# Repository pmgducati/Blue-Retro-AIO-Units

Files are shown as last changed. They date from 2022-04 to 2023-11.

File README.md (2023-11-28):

# Blue Retro AIO PCBs
This is a collection of PCBs that I made to work with darthcloud's BlueRetro Project. (https://github.com/darthcloud/BlueRetro)  The PCB's were created in Eagle and I have included the Gerbers if you would like to build them yourself. 

I have created PCB's for all supported systems with the exception of JVS.  An issue has been created for each of the systems that need testing.  If you make one please comment in the related issue on any progress/issues.

Currently, I am working on the Virtual Boy PCB, but need to find a cost efficient controller plug (I am not consolizing mine).  

Amaiorano wrote up a review for the variants that they built, you can read it here:
https://amaiorano.io/2023/11/06/blueretro-aio.html

Current status of all systems:


Here are some pics of the PCBs and Housings:









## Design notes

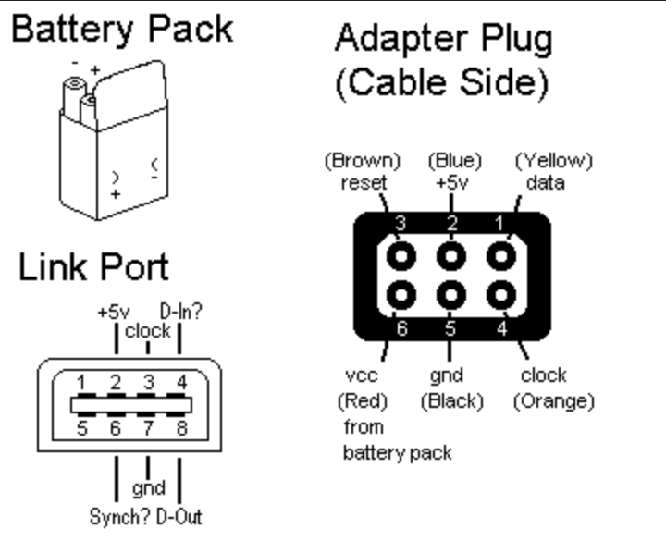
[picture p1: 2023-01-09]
Datasheets/Screenshot 2022-12-22 112040.png

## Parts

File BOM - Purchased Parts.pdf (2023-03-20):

Main PCB:
Part # | Digikey Part # | Description | Qty | ID | Notes | Link
DB25-PL-24 | 2057-DB25-PL-24-ND | DB25 Male solder cup | 1 | X1 | | https://www.digikey.com/en/products/detail/adam-tech/DB25-PL-24/9832321
ESP32-DEVKITC-32E | 1965-ESP32-DEVKITC-32E-ND | ESP32-WROOM-32E 4MB FLASH
LTST-C150TBKT | 160-1643-1-ND | Blue LED | 1 | LED1 | | https://www.digikey.com/en/products/detail/lite-on-inc/LTST-C150TBKT/388526
ERJ-8ENF84R5V | P84.5FCT-ND | 84.5 Ohm Resistor | 1 | R1 | | https://www.digikey.com/en/products/detail/panasonic-electronic-components/ERJ-8ENF84R5V/88656
801-43-019-10-001000 | ED6350-19-ND | CONN RCPT 19POS 0.1 GOLD PC | 2 | | Optional but recommended, if not using make sure the FW is good before soldering ESP32 to PCB | https://www.digikey.com/en/products/detail/mill-max-manufacturing-corp/801-43-019-10-001000/1212256
1 | U1 | ESP32 | https://www.digikey.com/en/products/detail/espressif-systems/ESP32-DEVKITC-32E/12091810

Atari 2600 (PP/OD)
Part # | Digikey Part # | Description | Qty | ID | Notes | Link
DB25-SL-24 | 2057-DB25-SL-24-ND | DB25 Female solder cup | 1 | X1 | | https://www.digikey.com/en/products/detail/adam-tech/DB25-SL-24/9832422
SN74AHCT125N | 296-4655-5-ND | 74AHCT125N DIP14 | 3 | U1,U2,U3 | | https://www.digikey.com/en/products/detail/texas-instruments/SN74AHCT125N/375798
| | Extension Cable | 2 | | Can Find Different options on Amazon | https://console5.com/store/atari-sega-commodore-coleco-msx-6-1-8m-joystick-controller-project-repair-cable-cord.html

Atari 7800
Part # | Digikey Part # | Description | Qty | ID | Notes | Link
DB25-SL-24 | 2057-DB25-SL-24-ND | DB25 Female solder cup | 1 | X1 | | https://www.digikey.com/en/products/detail/adam-tech/DB25-SL-24/9832422
SN74AHCT125N | 296-4655-5-ND | 74AHCT125N DIP14 | 3 | U1,U2,U3 | | https://www.digikey.com/en/products/detail/texas-instruments/SN74AHCT125N/375798
| | Extension Cable | 2 | | Can Find Different options on Amazon | https://console5.com/store/atari-sega-commodore-coleco-msx-6-1-8m-joystick-controller-project-repair-cable-cord.html

Atari Jaguar
Part # | Digikey Part # | Description | Qty | ID | Notes | Link
DB25-SL-24 | 2057-DB25-SL-24-ND | DB25 Female solder cup | 1 | X1 | | https://www.digikey.com/en/products/detail/adam-tech/DB25-SL-24/9832422
SN74AHCT125N | 296-4655-5-ND | 74AHCT125N DIP14 | 3 | U1,U2,U3 | | https://www.digikey.com/en/products/detail/texas-instruments/SN74AHCT125N/375798
| | Extension Cable | 1 | | | https://www.amazon.com/Tomee-Controller-Extension-not-machine-specific/dp/B07L6FC5R3

NEC PCEngine/TurboGrafx-16:
Part # | Digikey Part # | Description | Qty | ID | Notes | Link
DB25-SL-24 | 2057-DB25-SL-24-ND | DB25 Female solder cup | 1 | X1 | | https://www.digikey.com/en/products/detail/adam-tech/DB25-SL-24/9832422
SN74AHCT125N | 296-4655-5-ND | 74AHCT125N DIP14 | 2 | U1,U2 | | https://www.digikey.com/en/products/detail/texas-instruments/SN74AHCT125N/375798
RMCF1206FT47K0CT-ND | RMCF1206FT47K0 | 47K resistors | 2 | R1,R2 | | https://www.digikey.com/en/products/detail/stackpole-electronics-inc/RMCF1206FT47K0/1759490
| | Extension Cable | 1 | | PCE Option | https://console5.com/store/turbo-duo-pc-engine-5-1-5m-joystick-controller-extension-cable-cord-black.html
| | | | | TG16 Option | https://console5.com/store/turbografx-turbopad-repair-cable-tg16-turbo-grafx-controller-pad.html

NEC PC-FX
Part # | Digikey Part # | Description | Qty | ID | Notes | Link
DB25-SL-24 | 2057-DB25-SL-24-ND | DB25 Female solder cup | 1 | X1 | | https://www.digikey.com/en/products/detail/adam-tech/DB25-SL-24/9832422
SN74AHCT125N | 296-4655-5-ND | 74AHCT125N DIP14 | 2 | U1,U2 | | https://www.digikey.com/en/products/detail/texas-instruments/SN74AHCT125N/375798
| | Extension Cable | 1 | | Uses SNES Pins, But plug needs to be custom made | https://www.amazon.com/2Pack-Controller-Extension-Retro-Bit-Nintendo/dp/B075K4R86R

Nintendo 64:
Part # | Digikey Part # | Description | Qty | ID | Notes | Link
DB25-SL-24 | 2057-DB25-SL-24-ND | DB25 Female solder cup | 1 | X1 | | https://www.digikey.com/en/products/detail/adam-tech/DB25-SL-24/9832422
| | Extension Cable | 4 | | Can Find Different options on Amazon | https://console5.com/store/n64-nintendo-64-6-controller-extension-cable-tomee.html

Nintendo Gamecube:
Part # | Digikey Part # | Description | Qty | ID | Notes | Link
DB25-SL-24 | 2057-DB25-SL-24-ND | DB25 Female solder cup | 1 | X1 | | https://www.digikey.com/en/products/detail/adam-tech/DB25-SL-24/9832422
| | Extension Cable | 4 | | Can Find Different options on Amazon | https://console5.com/store/gamecube-wii-extension-cable-6-foot-1-8m-game-cube.html

Nintendo NES/Famicom:
Part # | Digikey Part # | Description | Qty | ID | Notes | Link
DB25-SL-24 | 2057-DB25-SL-24-ND | DB25 Female solder cup | 1 | X1 | | https://www.digikey.com/en/products/detail/adam-tech/DB25-SL-24/9832422
SN74AHCT125N | 296-4655-5-ND | 74AHCT125N DIP14 | 2 | U1,U2 | | https://www.digikey.com/en/products/detail/texas-instruments/SN74AHCT125N/375798
AC1206FR-073K6L | YAG5404CT-ND | 3.6K resistors | 3 | R1,R2,R3 | Optional, Only needed if using on PAL System | https://www.digikey.com/en/products/detail/yageo/AC1206FR-073K6L/5897510
| | Extension Cable | 2 | | Can Find Different options on Amazon | https://console5.com/store/nes-6-ft-extension-cable.html

Nintendo SNES/SFC
Part # | Digikey Part # | Description | Qty | ID | Notes | Link
DB25-SL-24 | 2057-DB25-SL-24-ND | DB25 Female solder cup | 1 | X1 | | https://www.digikey.com/en/products/detail/adam-tech/DB25-SL-24/9832422
SN74AHCT125N | 296-4655-5-ND | 74AHCT125N DIP14 | 3 | U1,U2 | | https://www.digikey.com/en/products/detail/texas-instruments/SN74AHCT125N/375798
| | Extension Cable | 2 | | Can Find Different options on Amazon, This is not a 7 Conductor Cable. For Multitap follow Darthcloud's Instructions:
| | | | | SNES controller plug (x2) (For multitap support 7 conductor are required, get a 3rd SNES extension for pin donation and use cable from PSX/Genesis/Saturn for the extra wires)

Nintendo Virtual Boy:
Part # | Digikey Part # | Description | Qty | ID | Notes | Link
DB25-SL-24 | 2057-DB25-SL-24-ND | DB25 Female solder cup | 1 | X1 | | https://www.digikey.com/en/products/detail/adam-tech/DB25-SL-24/9832422
SN74AHCT125N | 296-4655-5-ND | 74AHCT125N DIP14 | 2 | U1,U2 | | https://www.digikey.com/en/products/detail/texas-instruments/SN74AHCT125N/375798
PJ-202B | CP-202B-ND | Barrel jack 5.5mm/2.1mm | 1 | CN1 | | https://www.digikey.com/en/products/detail/cui-devices/PJ-202B/252008
? | ? | DPST switch | 1 | S1 | Pulled from Stock, Need to find actual P/N
1N5400RLG | 1N5400RLGOSCT-ND | 1N5400 diode | 1 | D1 | | https://www.digikey.com/en/products/detail/onsemi/1N5400RLG/893867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
| | 9V PSU 5.5mm/2.1mm center po | 1 | | | https://console5.com/store/9v-1300ma-ul-certified-power-supply-transformer-for-sega-genesis-cd-nes-aes-tg16-100v-240v.html
14-CRIMP-PIN-FEMALE-200PK | | D Sub Female Crimp On Cable | 6 | | | https://www.amazon.com/gp/product/B00EDG0KI4/ref=ox_sc_act_title_1?smid=A64W1E1ZZHST0&psc=1
MXT1001MBK | | 1M DB9 Cable | 1 | | | https://www.amazon.com/gp/product/B00A6GIUNC/ref=ox_sc_act_title_2?smid=ATVPDKIKX0DER&th=1

Nintendo Wii Ext & NES/SNES Mini:
Part # | Digikey Part # | Description | Qty | ID | Notes | Link
DB25-SL-24 | 2057-DB25-SL-24-ND | DB25 Female solder cup | 1 | X1 | | https://www.digikey.com/en/products/detail/adam-tech/DB25-SL-24/9832422
RMCF1206JT1K00 | RMCF1206JT1K00TR-ND | 1K Resistors | 4 | R1,R2,R3,R4 | | https://www.digikey.com/en/products/detail/stackpole-electronics-inc/RMCF1206JT1K00/1757526
USB4085-GF-A | 2073-USB4085-GF-ATR-ND | Female USB-C Plug | 1 | J1 | | https://www.digikey.com/en/products/detail/gct/USB4085-GF-A/9859662
NA | NA | SNES/NES Mini Extension | 2 | | Can Find Different options on Amazon | https://a.co/d/1FtFBEe

https://console5.com/store/snes-controller-extension-cable-6-foot-1-8m.html

Panasonic 3DO:
Part # | Digikey Part # | Description | Qty | ID | Notes | Link
DB25-SL-24 | 2057-DB25-SL-24-ND | DB25 Female solder cup | 1 | X1 | | https://www.digikey.com/en/products/detail/adam-tech/DB25-SL-24/9832422
SN74AHCT125N | 296-4655-5-ND | 74AHCT125N DIP14 | 2 | U1,U2 | | https://www.digikey.com/en/products/detail/texas-instruments/SN74AHCT125N/375798
| | Extension Cable | 1 | | Can Find Different options on Amazon | https://console5.com/store/atari-sega-commodore-coleco-msx-6-1-8m-joystick-controller-project-repair-cable-cord.html

Phillips CD-i
Part # | Digikey Part # | Description | Qty | ID | Notes | Link
DB25-SL-24 | 2057-DB25-SL-24-ND | DB25 Female solder cup | 1 | X1 | | https://www.digikey.com/en/products/detail/adam-tech/DB25-SL-24/9832422
SN74AHCT125N | 296-4655-5-ND | 74AHCT125N DIP14 | 2 | U1,U2 | | https://www.digikey.com/en/products/detail/texas-instruments/SN74AHCT125N/375798
54-00019 | 54-00019T-ND | USB-Mini B | 1 | CNT1 | https://www.digikey.com/en/products/detail/tensility-international-corp/54-00019/6056083
| | Extension Cable | 2 | | https://console5.com/store/turbo-duo-pc-engine-5-1-5m-joystick-controller-extension-cable-cord-black.html

Sega Dreamcast
Part # | Digikey Part # | Description | Qty | ID | Notes | Link
DB25-SL-24 | 2057-DB25-SL-24-ND | DB25 Female solder cup | 1 | X1 | | https://www.digikey.com/en/products/detail/adam-tech/DB25-SL-24/9832422
| | Extension Cable | 4 | | Can Find Different options on Amazon | https://retro-bit.com/dreamcast-controller-extension-cable.html

Sega Genesis/Megadrive
Part # | Digikey Part # | Description | Qty | ID | Notes | Link
DB25-SL-24 | 2057-DB25-SL-24-ND | DB25 Female solder cup | 1 | X1 | | https://www.digikey.com/en/products/detail/adam-tech/DB25-SL-24/9832422
SN74AHCT125N | 296-4655-5-ND | 74AHCT125N DIP14 | 4 | U1,U2,U3,U4 | | https://www.digikey.com/en/products/detail/texas-instruments/SN74AHCT125N/375798
| | Extension Cable | 2 | | Can Find Different options on Amazon | https://console5.com/store/atari-sega-commodore-coleco-msx-6-1-8m-joystick-controller-project-repair-cable-cord.html

Sega Genesis/Megadrive (Multitap)
Part # | Digikey Part # | Description | Qty | ID | Notes | Link
DB25-SL-24 | 2057-DB25-SL-24-ND | DB25 Female solder cup | 1 | X1 | | https://www.digikey.com/en/products/detail/adam-tech/DB25-SL-24/9832422
SN74AHCT125N | 296-4655-5-ND | 74AHCT125N DIP14 | 4 | U1,U3,U5,U6 | | https://www.digikey.com/en/products/detail/texas-instruments/SN74AHCT125N/375798
SN74AHCT126N | 296-4659-5-ND | 74AHCT126N DIP14 | 1 | U2 | | https://www.digikey.com/en/products/detail/texas-instruments/SN74AHCT126N/13473330
SN74AHCT32N | 296-4732-5-ND | 74AHCT32N DIP14 | 1 | U4 | | https://www.digikey.com/en/products/detail/texas-instruments/SN74AHCT32N/13438952
| | Extension Cable | 2 | | Can Find Different options on Amazon | https://console5.com/store/atari-sega-commodore-coleco-msx-6-1-8m-joystick-controller-project-repair-cable-cord.html

Sega Saturn:
Part # | Digikey Part # | Description | Qty | ID | Notes | Link
DB25-SL-24 | 2057-DB25-SL-24-ND | DB25 Female solder cup | 1 | X1 | | https://www.digikey.com/en/products/detail/adam-tech/DB25-SL-24/9832422
SN74AHCT125N | 296-4655-5-ND | 74AHCT125N DIP14 | 4 | U1A,U2A,U3A,U4A | | https://www.digikey.com/en/products/detail/texas-instruments/SN74AHCT125N/375798
| | Extension Cable | 2 | | | https://console5.com/store/sega-saturn-controller-tinned-wire-repair-cable-6-foot-1-8m.html

Sega SG1000/SMS (OD/PP)
Part # | Digikey Part # | Description | Qty | ID | Notes | Link
DB25-SL-24 | 2057-DB25-SL-24-ND | DB25 Female solder cup | 1 | X1 | | https://www.digikey.com/en/products/detail/adam-tech/DB25-SL-24/9832422
SN74AHCT125N | 296-4655-5-ND | 74AHCT125N DIP14 | 3 | U1,U2 | | https://www.digikey.com/en/products/detail/texas-instruments/SN74AHCT125N/375798
| | Extension Cable | 2 | | Can Find Different options on Amazon | https://console5.com/store/atari-sega-commodore-coleco-msx-6-1-8m-joystick-controller-project-repair-cable-cord.html

SNK NeoGeo/JAMMA/Supergun (PP/OD)
Part # | Digikey Part # | Description | Qty | ID | Notes | Link
DB25-SL-24 | 2057-DB25-SL-24-ND | DB25 Female solder cup | 1 | X1 | | https://www.digikey.com/en/products/detail/adam-tech/DB25-SL-24/9832422
SN74AHCT125N | 296-4655-5-ND | 74AHCT125N DIP14 | 3 | U1,U2,U# | | https://www.digikey.com/en/products/detail/texas-instruments/SN74AHCT125N/375798
| | Extension Cable | 1 | | | https://www.amazon.com/Tomee-Controller-Extension-not-machine-specific/dp/B07L6FC5R3

Sony PSX/PS2:
Part # | Digikey Part # | Description | Qty | ID | Notes | Link
DB25-SL-24 | 2057-DB25-SL-24-ND | DB25 Female solder cup | 1 | X1 | | https://www.digikey.com/en/products/detail/adam-tech/DB25-SL-24/9832422
| | Extension Cable | 2 | | Can Find Different options on Amazon | https://console5.com/store/playstation-1-2-controller-extension-cable-6-ps1-ps2-tomee.html

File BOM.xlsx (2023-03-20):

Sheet: PCB Parts and Cables
Main PCB:
Part # | Digikey Part # | Description | Qty | ID | Notes | Link
DB25-PL-24 | 2057-DB25-PL-24-ND | DB25 Male solder cup | 1 | X1 |  | https://www.digikey.com/en/products/detail/adam-tech/DB25-PL-24/9832321
ESP32-DEVKITC-32E | 1965-ESP32-DEVKITC-32E-ND | ESP32-WROOM-32E 4MB FLASH | 1 | U1 | ESP32 | https://www.digikey.com/en/products/detail/espressif-systems/ESP32-DEVKITC-32E/12091810
LTST-C150TBKT | 160-1643-1-ND | Blue LED | 1 | LED1 |  | https://www.digikey.com/en/products/detail/lite-on-inc/LTST-C150TBKT/388526
ERJ-8ENF84R5V | P84.5FCT-ND | 84.5 Ohm Resistor | 1 | R1 |  | https://www.digikey.com/en/products/detail/panasonic-electronic-components/ERJ-8ENF84R5V/88656
801-43-019-10-001000 | ED6350-19-ND | CONN RCPT 19POS 0.1 GOLD PCB | 2 |  | Optional but recommended, if not using make sure the FW is good before soldering ESP32 to PCB | https://www.digikey.com/en/products/detail/mill-max-manufacturing-corp/801-43-019-10-001000/1212256
Atari 2600 (PP/OD)
Part # | Digikey Part # | Description | Qty | ID | Notes | Link
DB25-SL-24 | 2057-DB25-SL-24-ND | DB25 Female solder cup | 1 | X1 |  | https://www.digikey.com/en/products/detail/adam-tech/DB25-SL-24/9832422
SN74AHCT125N | 296-4655-5-ND | 74AHCT125N DIP14 | 3 | U1,U2,U3 |  | https://www.digikey.com/en/products/detail/texas-instruments/SN74AHCT125N/375798
 |  | Extension Cable | 2 |  | Can Find Different options on Amazon | https://console5.com/store/atari-sega-commodore-coleco-msx-6-1-8m-joystick-controller-project-repair-cable-cord.html
Atari 7800
Part # | Digikey Part # | Description | Qty | ID | Notes | Link
DB25-SL-24 | 2057-DB25-SL-24-ND | DB25 Female solder cup | 1 | X1 |  | https://www.digikey.com/en/products/detail/adam-tech/DB25-SL-24/9832422
SN74AHCT125N | 296-4655-5-ND | 74AHCT125N DIP14 | 3 | U1,U2,U3 |  | https://www.digikey.com/en/products/detail/texas-instruments/SN74AHCT125N/375798
 |  | Extension Cable | 2 |  | Can Find Different options on Amazon | https://console5.com/store/atari-sega-commodore-coleco-msx-6-1-8m-joystick-controller-project-repair-cable-cord.html
Atari Jaguar
Part # | Digikey Part # | Description | Qty | ID | Notes | Link
DB25-SL-24 | 2057-DB25-SL-24-ND | DB25 Female solder cup | 1 | X1 |  | https://www.digikey.com/en/products/detail/adam-tech/DB25-SL-24/9832422
SN74AHCT125N | 296-4655-5-ND | 74AHCT125N DIP14 | 3 | U1,U2,U3 |  | https://www.digikey.com/en/products/detail/texas-instruments/SN74AHCT125N/375798
 |  | Extension Cable | 1 |  |  | https://www.amazon.com/Tomee-Controller-Extension-not-machine-specific/dp/B07L6FC5R3
NEC PCEngine/TurboGrafx-16:
Part # | Digikey Part # | Description | Qty | ID | Notes | Link
DB25-SL-24 | 2057-DB25-SL-24-ND | DB25 Female solder cup | 1 | X1 |  | https://www.digikey.com/en/products/detail/adam-tech/DB25-SL-24/9832422
SN74AHCT125N | 296-4655-5-ND | 74AHCT125N DIP14 | 2 | U1,U2 |  | https://www.digikey.com/en/products/detail/texas-instruments/SN74AHCT125N/375798
RMCF1206FT47K0CT-ND | RMCF1206FT47K0 | 47K resistors | 2 | R1,R2 |  | https://www.digikey.com/en/products/detail/stackpole-electronics-inc/RMCF1206FT47K0/1759490
 |  | Extension Cable | 1 |  | PCE Option | https://console5.com/store/turbo-duo-pc-engine-5-1-5m-joystick-controller-extension-cable-cord-black.html
 |  |  |  |  | TG16 Option | https://console5.com/store/turbografx-turbopad-repair-cable-tg16-turbo-grafx-controller-pad.html
NEC PC-FX
Part # | Digikey Part # | Description | Qty | ID | Notes | Link
DB25-SL-24 | 2057-DB25-SL-24-ND | DB25 Female solder cup | 1 | X1 |  | https://www.digikey.com/en/products/detail/adam-tech/DB25-SL-24/9832422
SN74AHCT125N | 296-4655-5-ND | 74AHCT125N DIP14 | 2 | U1,U2 |  | https://www.digikey.com/en/products/detail/texas-instruments/SN74AHCT125N/375798
 |  | Extension Cable | 1 |  | Uses SNES Pins, But plug needs to be custom made | https://www.amazon.com/2Pack-Controller-Extension-Retro-Bit-Nintendo/dp/B075K4R86R
Nintendo 64:
Part # | Digikey Part # | Description | Qty | ID | Notes | Link
DB25-SL-24 | 2057-DB25-SL-24-ND | DB25 Female solder cup | 1 | X1 |  | https://www.digikey.com/en/products/detail/adam-tech/DB25-SL-24/9832422
 |  | Extension Cable | 4 |  | Can Find Different options on Amazon | https://console5.com/store/n64-nintendo-64-6-controller-extension-cable-tomee.html
Nintendo Gamecube:
Part # | Digikey Part # | Description | Qty | ID | Notes | Link
DB25-SL-24 | 2057-DB25-SL-24-ND | DB25 Female solder cup | 1 | X1 |  | https://www.digikey.com/en/products/detail/adam-tech/DB25-SL-24/9832422
 |  | Extension Cable | 4 |  | Can Find Different options on Amazon | https://console5.com/store/gamecube-wii-extension-cable-6-foot-1-8m-game-cube.html
Nintendo NES/Famicom:
Part # | Digikey Part # | Description | Qty | ID | Notes | Link
DB25-SL-24 | 2057-DB25-SL-24-ND | DB25 Female solder cup | 1 | X1 |  | https://www.digikey.com/en/products/detail/adam-tech/DB25-SL-24/9832422
SN74AHCT125N | 296-4655-5-ND | 74AHCT125N DIP14 | 2 | U1,U2 |  | https://www.digikey.com/en/products/detail/texas-instruments/SN74AHCT125N/375798
AC1206FR-073K6L | YAG5404CT-ND | 3.6K resistors | 3 | R1,R2,R3 | Optional, Only needed if using on PAL System | https://www.digikey.com/en/products/detail/yageo/AC1206FR-073K6L/5897510
 |  | Extension Cable | 2 |  | Can Find Different options on Amazon | https://console5.com/store/nes-6-ft-extension-cable.html
Nintendo SNES/SFC
Part # | Digikey Part # | Description | Qty | ID | Notes | Link
DB25-SL-24 | 2057-DB25-SL-24-ND | DB25 Female solder cup | 1 | X1 |  | https://www.digikey.com/en/products/detail/adam-tech/DB25-SL-24/9832422
SN74AHCT125N | 296-4655-5-ND | 74AHCT125N DIP14 | 3 | U1,U2 |  | https://www.digikey.com/en/products/detail/texas-instruments/SN74AHCT125N/375798
 |  | Extension Cable | 2 |  | Can Find Different options on Amazon, This is not a 7 Conductor Cable. For Multitap follow Darthcloud's Instructions: | https://console5.com/store/snes-controller-extension-cable-6-foot-1-8m.html
 |  |  |  |  | SNES controller plug (x2) (For multitap support 7 conductor are required, get a 3rd SNES extension for pin donation and use cable from PSX/Genesis/Saturn for the extra wires)
Nintendo Virtual Boy:
Part # | Digikey Part # | Description | Qty | ID | Notes | Link
DB25-SL-24 | 2057-DB25-SL-24-ND | DB25 Female solder cup | 1 | X1 |  | https://www.digikey.com/en/products/detail/adam-tech/DB25-SL-24/9832422
SN74AHCT125N | 296-4655-5-ND | 74AHCT125N DIP14 | 2 | U1,U2 |  | https://www.digikey.com/en/products/detail/texas-instruments/SN74AHCT125N/375798
PJ-202B | CP-202B-ND | Barrel jack 5.5mm/2.1mm | 1 | CN1 |  | https://www.digikey.com/en/products/detail/cui-devices/PJ-202B/252008
? | ? | DPST switch | 1 | S1 | Pulled from Stock, Need to find actual P/N
1N5400RLG | 1N5400RLGOSCT-ND | 1N5400 diode | 1 | D1 |  | https://www.digikey.com/en/products/detail/onsemi/1N5400RLG/893867
 |  | 9V PSU 5.5mm/2.1mm center positive | 1 |  |  | https://console5.com/store/9v-1300ma-ul-certified-power-supply-transformer-for-sega-genesis-cd-nes-aes-tg16-100v-240v.html
14-CRIMP-PIN-FEMALE-200PK |  | D Sub Female Crimp On Cable | 6 |  |  | https://www.amazon.com/gp/product/B00EDG0KI4/ref=ox_sc_act_title_1?smid=A64W1E1ZZHST0&psc=1
MXT1001MBK |  | 1M DB9 Cable | 1 |  |  | https://www.amazon.com/gp/product/B00A6GIUNC/ref=ox_sc_act_title_2?smid=ATVPDKIKX0DER&th=1
Nintendo Wii Ext & NES/SNES Mini:
Part # | Digikey Part # | Description | Qty | ID | Notes | Link
DB25-SL-24 | 2057-DB25-SL-24-ND | DB25 Female solder cup | 1 | X1 |  | https://www.digikey.com/en/products/detail/adam-tech/DB25-SL-24/9832422
RMCF1206JT1K00 | RMCF1206JT1K00TR-ND | 1K Resistors | 4 | R1,R2,R3,R4 |  | https://www.digikey.com/en/products/detail/stackpole-electronics-inc/RMCF1206JT1K00/1757526
USB4085-GF-A | 2073-USB4085-GF-ATR-ND | Female USB-C Plug | 1 | J1 |  | https://www.digikey.com/en/products/detail/gct/USB4085-GF-A/9859662
NA | NA | SNES/NES Mini Extension | 2 |  | Can Find Different options on Amazon | https://a.co/d/1FtFBEe
Panasonic 3DO:
Part # | Digikey Part # | Description | Qty | ID | Notes | Link
DB25-SL-24 | 2057-DB25-SL-24-ND | DB25 Female solder cup | 1 | X1 |  | https://www.digikey.com/en/products/detail/adam-tech/DB25-SL-24/9832422
SN74AHCT125N | 296-4655-5-ND | 74AHCT125N DIP14 | 2 | U1,U2 |  | https://www.digikey.com/en/products/detail/texas-instruments/SN74AHCT125N/375798
 |  | Extension Cable | 1 |  | Can Find Different options on Amazon | https://console5.com/store/atari-sega-commodore-coleco-msx-6-1-8m-joystick-controller-project-repair-cable-cord.html
Phillips CD-i
Part # | Digikey Part # | Description | Qty | ID | Notes | Link
DB25-SL-24 | 2057-DB25-SL-24-ND | DB25 Female solder cup | 1 | X1 |  | https://www.digikey.com/en/products/detail/adam-tech/DB25-SL-24/9832422
SN74AHCT125N | 296-4655-5-ND | 74AHCT125N DIP14 | 2 | U1,U2 |  | https://www.digikey.com/en/products/detail/texas-instruments/SN74AHCT125N/375798
54-00019 | 54-00019T-ND | USB-Mini B | 1 | CNT1 |  | https://www.digikey.com/en/products/detail/tensility-international-corp/54-00019/6056083
 |  | Extension Cable | 2 |  |  | https://console5.com/store/turbo-duo-pc-engine-5-1-5m-joystick-controller-extension-cable-cord-black.html
Sega Dreamcast
Part # | Digikey Part # | Description | Qty | ID | Notes | Link
DB25-SL-24 | 2057-DB25-SL-24-ND | DB25 Female solder cup | 1 | X1 |  | https://www.digikey.com/en/products/detail/adam-tech/DB25-SL-24/9832422
 |  | Extension Cable | 4 |  | Can Find Different options on Amazon | https://retro-bit.com/dreamcast-controller-extension-cable.html
Sega Genesis/Megadrive
Part # | Digikey Part # | Description | Qty | ID | Notes | Link
DB25-SL-24 | 2057-DB25-SL-24-ND | DB25 Female solder cup | 1 | X1 |  | https://www.digikey.com/en/products/detail/adam-tech/DB25-SL-24/9832422
SN74AHCT125N | 296-4655-5-ND | 74AHCT125N DIP14 | 4 | U1,U2,U3,U4 |  | https://www.digikey.com/en/products/detail/texas-instruments/SN74AHCT125N/375798
 |  | Extension Cable | 2 |  | Can Find Different options on Amazon | https://console5.com/store/atari-sega-commodore-coleco-msx-6-1-8m-joystick-controller-project-repair-cable-cord.html
Sega Genesis/Megadrive (Multitap)
Part # | Digikey Part # | Description | Qty | ID | Notes | Link
DB25-SL-24 | 2057-DB25-SL-24-ND | DB25 Female solder cup | 1 | X1 |  | https://www.digikey.com/en/products/detail/adam-tech/DB25-SL-24/9832422
SN74AHCT125N | 296-4655-5-ND | 74AHCT125N DIP14 | 4 | U1,U3,U5,U6 |  | https://www.digikey.com/en/products/detail/texas-instruments/SN74AHCT125N/375798
SN74AHCT126N | 296-4659-5-ND | 74AHCT126N DIP14 | 1 | U2 |  | https://www.digikey.com/en/products/detail/texas-instruments/SN74AHCT126N/13473330
SN74AHCT32N | 296-4732-5-ND | 74AHCT32N DIP14 | 1 | U4 |  | https://www.digikey.com/en/products/detail/texas-instruments/SN74AHCT32N/13438952
 |  | Extension Cable | 2 |  | Can Find Different options on Amazon | https://console5.com/store/atari-sega-commodore-coleco-msx-6-1-8m-joystick-controller-project-repair-cable-cord.html
Sega Saturn:
Part # | Digikey Part # | Description | Qty | ID | Notes | Link
DB25-SL-24 | 2057-DB25-SL-24-ND | DB25 Female solder cup | 1 | X1 |  | https://www.digikey.com/en/products/detail/adam-tech/DB25-SL-24/9832422
SN74AHCT125N | 296-4655-5-ND | 74AHCT125N DIP14 | 4 | U1A,U2A,U3A,U4A |  | https://www.digikey.com/en/products/detail/texas-instruments/SN74AHCT125N/375798
 |  | Extension Cable | 2 |  |  | https://console5.com/store/sega-saturn-controller-tinned-wire-repair-cable-6-foot-1-8m.html
Sega SG1000/SMS (OD/PP)
Part # | Digikey Part # | Description | Qty | ID | Notes | Link
DB25-SL-24 | 2057-DB25-SL-24-ND | DB25 Female solder cup | 1 | X1 |  | https://www.digikey.com/en/products/detail/adam-tech/DB25-SL-24/9832422
SN74AHCT125N | 296-4655-5-ND | 74AHCT125N DIP14 | 3 | U1,U2 |  | https://www.digikey.com/en/products/detail/texas-instruments/SN74AHCT125N/375798
 |  | Extension Cable | 2 |  | Can Find Different options on Amazon | https://console5.com/store/atari-sega-commodore-coleco-msx-6-1-8m-joystick-controller-project-repair-cable-cord.html
SNK NeoGeo/JAMMA/Supergun (PP/OD)
Part # | Digikey Part # | Description | Qty | ID | Notes | Link
DB25-SL-24 | 2057-DB25-SL-24-ND | DB25 Female solder cup | 1 | X1 |  | https://www.digikey.com/en/products/detail/adam-tech/DB25-SL-24/9832422
SN74AHCT125N | 296-4655-5-ND | 74AHCT125N DIP14 | 3 | U1,U2,U# |  | https://www.digikey.com/en/products/detail/texas-instruments/SN74AHCT125N/375798
 |  | Extension Cable | 1 |  |  | https://www.amazon.com/Tomee-Controller-Extension-not-machine-specific/dp/B07L6FC5R3
Sony PSX/PS2:
Part # | Digikey Part # | Description | Qty | ID | Notes | Link
DB25-SL-24 | 2057-DB25-SL-24-ND | DB25 Female solder cup | 1 | X1 |  | https://www.digikey.com/en/products/detail/adam-tech/DB25-SL-24/9832422
 |  | Extension Cable | 2 |  | Can Find Different options on Amazon | https://console5.com/store/playstation-1-2-controller-extension-cable-6-ps1-ps2-tomee.html

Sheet: 3D Printed Parts
Main PCB:
Blue Retro Main Housing Bottom
Blue Retro Main Housing Top
Atari 2600 (PP/OD)
Aux Bottom - 2 Player
Aux Top - Atari 2600
Atari 7800
Aux Bottom - 2 Player
Aux Top - Atari 7800
Atari Jaguar
Aux Bottom - 2 Player
Aux Top - Atari Jaguar
NEC PCEngine/TurboGrafx-16:
Aux Bottom - 1 Player
Aux Top - NEC TurboGrafx-16 or Aux Top - NEC PCEngine
NEC PC-FX
Aux Bottom - 1 Player
Aux Top - NEC PC-FX
Nintendo 64:
Aux Bottom - 4 Player
Aux Top - Nintendo 64
Nintendo Gamecube:
Aux Bottom - 4 Player
Aux Top - Nintendo Gamecube
Nintendo NES/Famicom:
Aux Bottom - 2 Player
Aux Top - Nintendo NES or Aux Top - Nintendo Famicom
Nintendo SNES/SFC
Aux Bottom - 2 Player
Aux Top - Nintendo SNES or Aux Top - Nintendo SFC
Nintendo Virtual Boy:
Aux Bottom - Nintendo Virtual Boy
Aux Top - Nintendo Virtual Boy
VB-ext-center-male-BOT-REV7
VB-ext-center-male-REV7
VB-ext-center-male-TOP-REV7
Nintendo Wii Ext & NES/SNES Mini:
Aux Bottom - Nintendo Wii,Wii Ext,Classics (NES,SNES,FC,SFC)
Aux Top - Nintendo Wii or Aux Top - Nintendo Wii Ext or Aux Top - Nintendo SNES Classic or Aux Top - Nintendo SFC Classic or Aux Top - Nintendo NES Classic or Aux Top - Nintendo Famicom Classic
Panasonic 3DO:
Aux Top - Panasonic 3DO
Aux Bottom - Panasonic 3DO
Phillips CD-i
Aux Bottom - Phillips CD-i
Aux Top - Phillips CD-i
Sega Dreamcast
Aux Bottom - 4 Player
Aux Top - Sega Dreamcast
Sega Genesis/Megadrive
Aux Bottom - 2 Player
Aux Top - Sega Genesis or Aux Top - Sega Megadrive
Sega Genesis/Megadrive (Multitap)
Aux Bottom - Sega Genesis-Megadrive Multitap
Aux Top - Sega Genesis - Multitap or Aux Top - Sega Megadrive - Multitap
Sega Saturn:
Aux Bottom - 2 Player
Aux Top - Sega Saturn
Sega SG1000/SMS (OD/PP)
Aux Bottom - 2 Player
Aux Top - Sega SG-1000 or Aux Top - Sega Master System
SNK NeoGeo/JAMMA/Supergun (PP/OD)
Aux Bottom - 1 Player
Aux Top - SNK Neo Geo
Sony PSX/PS2:
Aux Bottom - 2 Player
Aux Top - Sony PSX-PS2

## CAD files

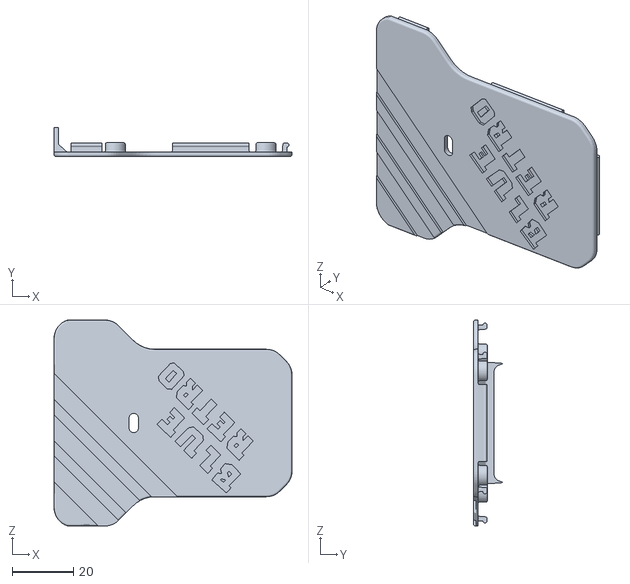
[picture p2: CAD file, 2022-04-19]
STL/Blue Retro Main Housing Top.STL
77.4 x 9.45 x 67.0

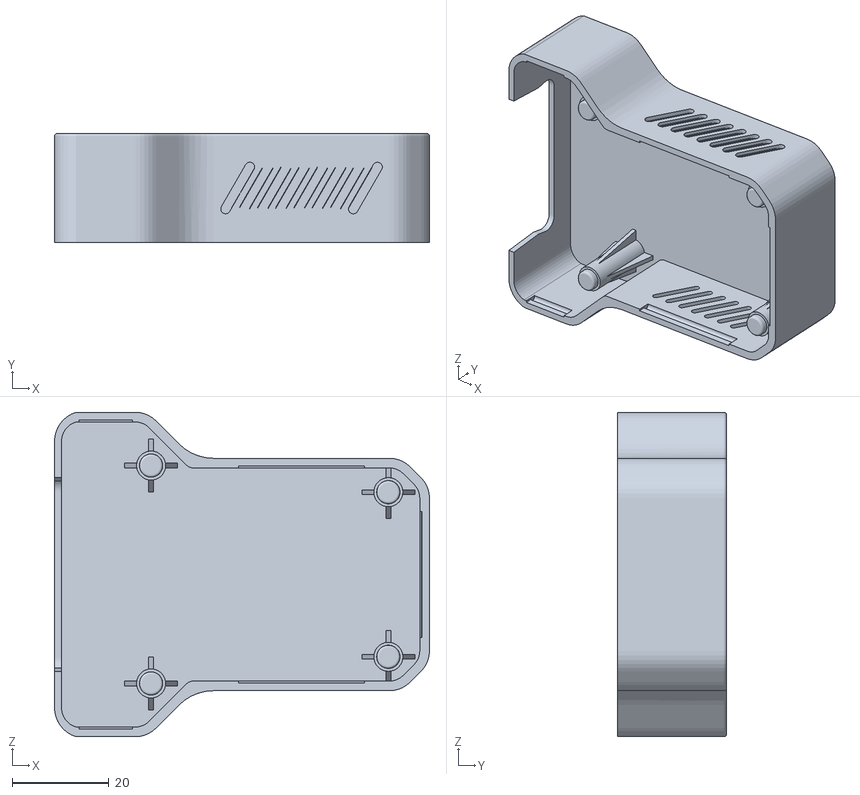
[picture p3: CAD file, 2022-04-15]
STL/Blue Retro Main Housing Bottom.STL
77.4 x 22.6 x 67.0

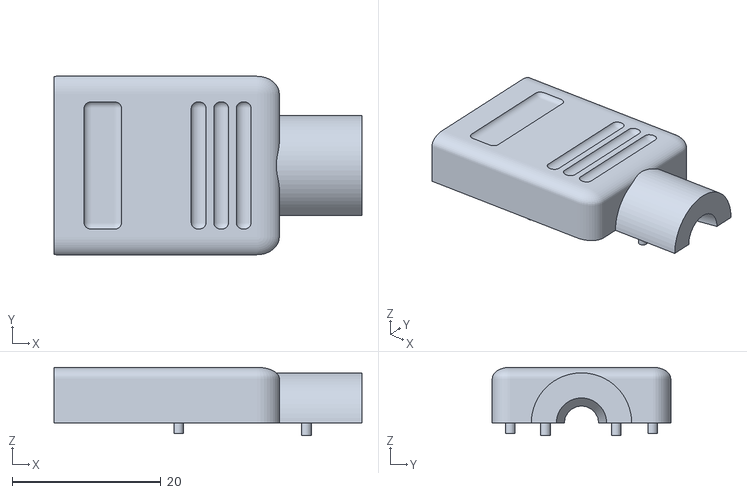
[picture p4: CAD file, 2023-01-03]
STL/VB-ext-center-male-TOP-REV7.stl
41.4 x 24.0 x 9.20

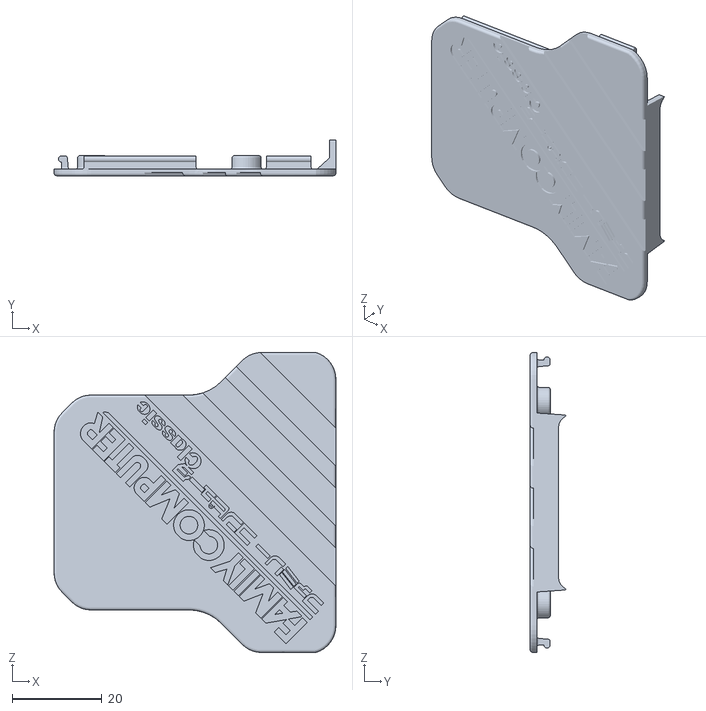
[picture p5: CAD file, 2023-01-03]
STL/Aux Top - Nintendo Famicom Classic.STL
63.0 x 7.96 x 67.0

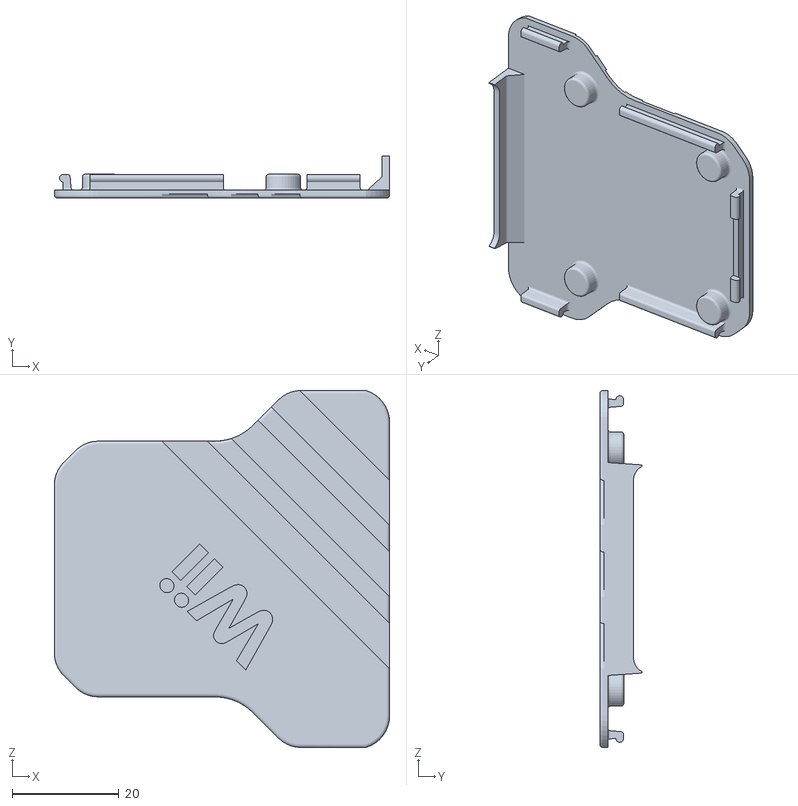
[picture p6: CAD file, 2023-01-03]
STL/Aux Top - Nintendo Wii.STL
63.0 x 7.96 x 67.0

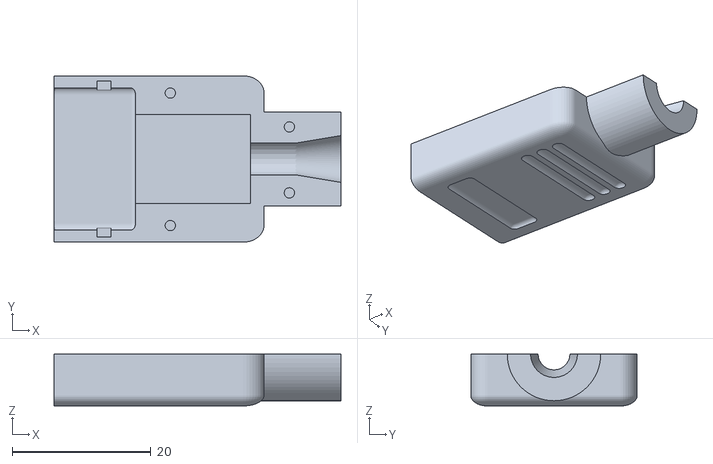
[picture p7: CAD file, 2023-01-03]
STL/VB-ext-center-male-BOT-REV7.stl
41.4 x 24.0 x 7.50

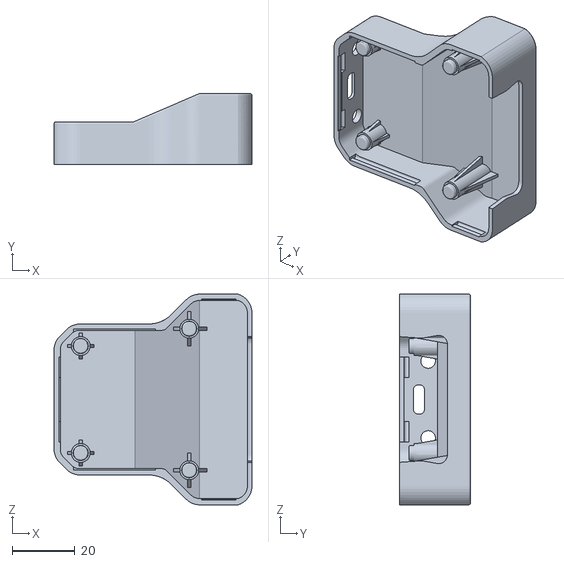
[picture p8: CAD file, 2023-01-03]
STL/Aux Bottom - Nintendo Wii,Wii Ext,Classics (NES,SNES,FC,SFC).STL
63.0 x 22.6 x 67.0

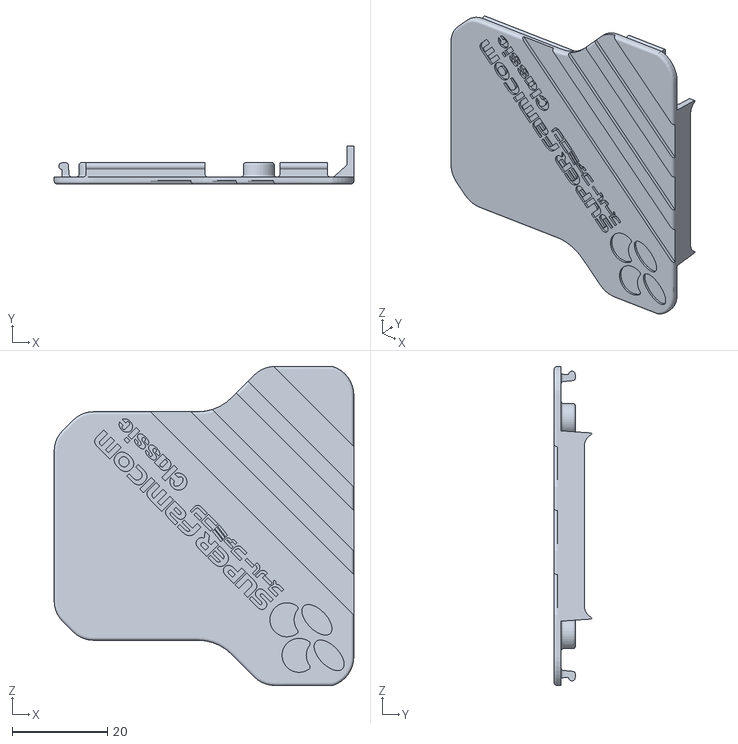
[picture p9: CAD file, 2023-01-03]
STL/Aux Top - Nintendo SFC Classic.STL
63.0 x 7.96 x 67.0

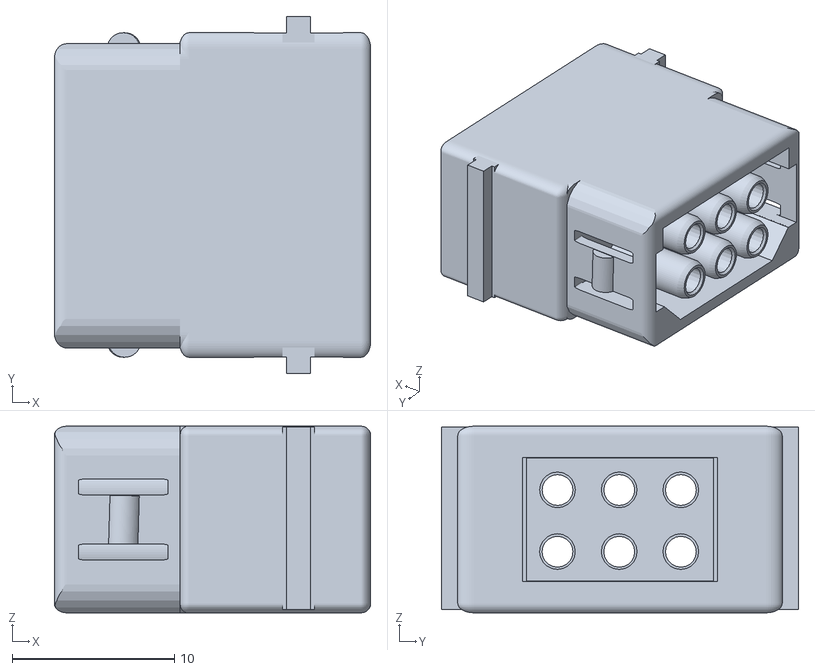
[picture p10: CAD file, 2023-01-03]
STL/VB-ext-center-male-REV7.stl
19.5 x 22.0 x 11.5

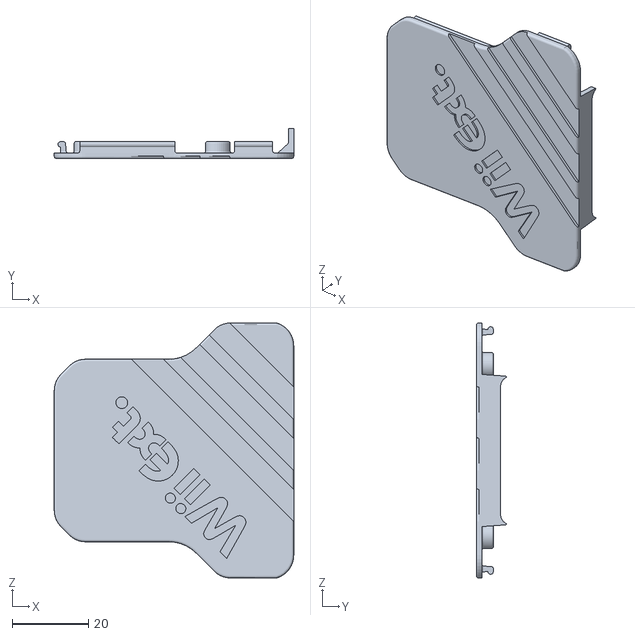
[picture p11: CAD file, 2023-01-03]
STL/Aux Top - Nintendo Wii Ext.STL
63.0 x 7.96 x 67.0

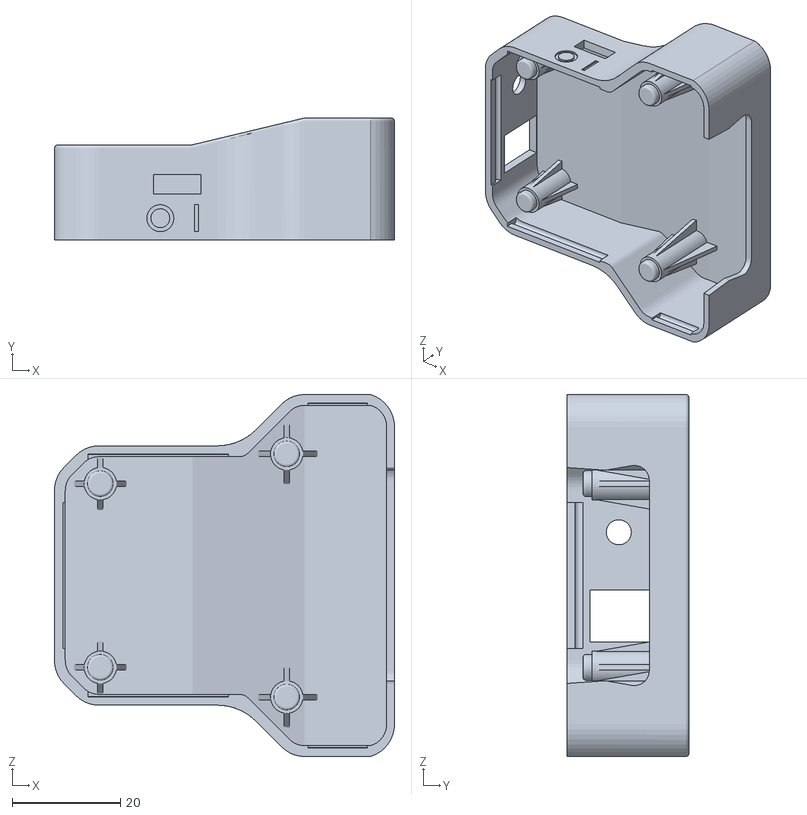
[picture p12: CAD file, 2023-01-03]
STL/Aux Bottom - Nintendo Virtual Boy.STL
63.0 x 22.6 x 67.0

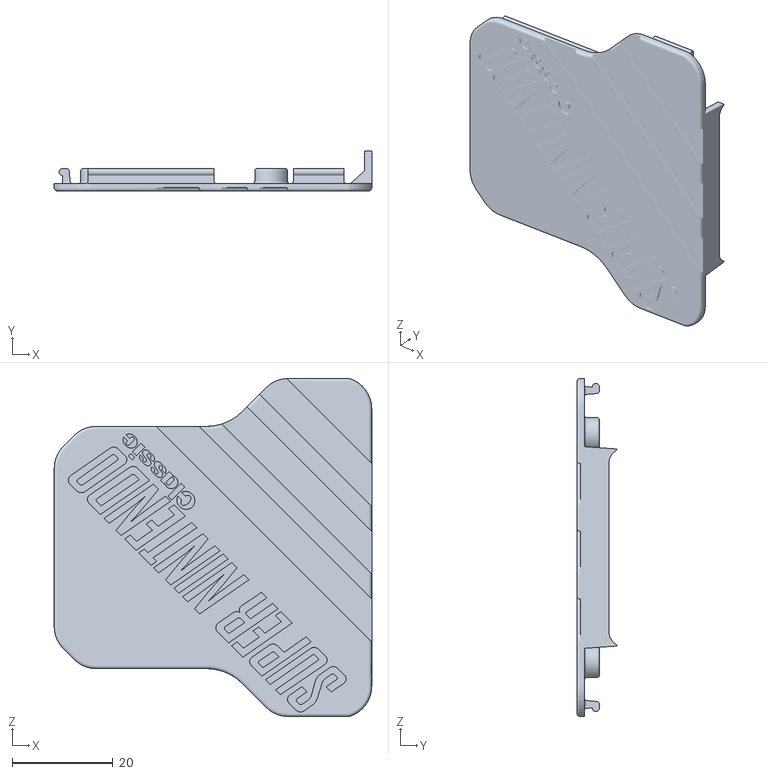
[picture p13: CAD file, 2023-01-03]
STL/Aux Top - Nintendo SNES Classic.STL
63.0 x 7.96 x 67.0

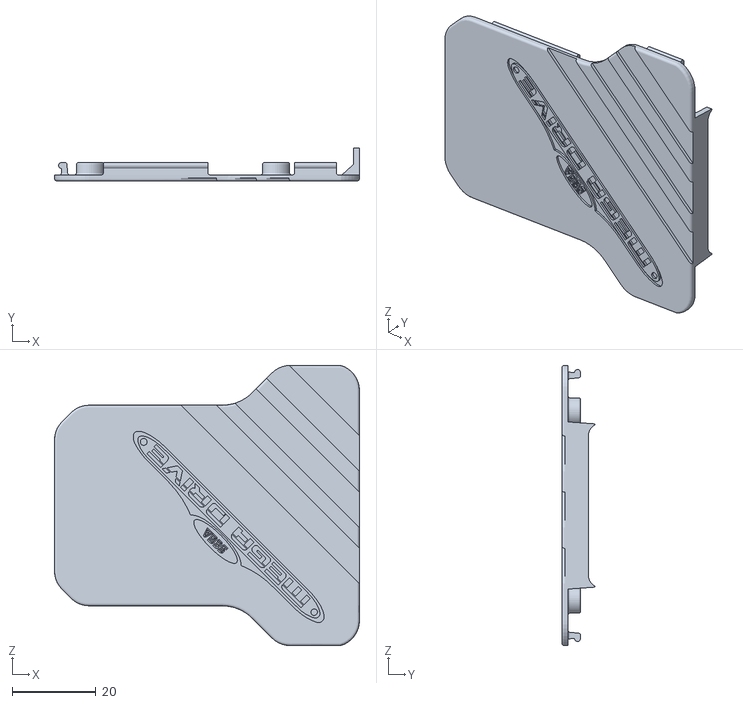
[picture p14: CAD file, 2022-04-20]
STL/Aux Top - Sega Megadrive - Multitap.STL
72.9 x 7.96 x 67.0

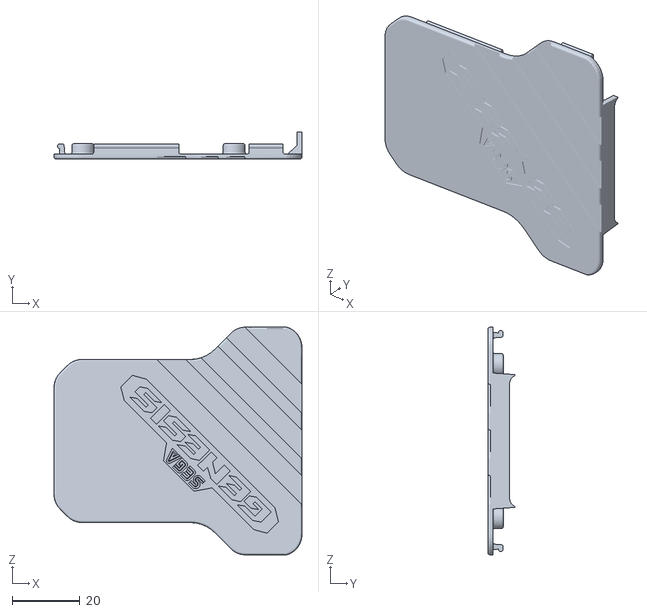
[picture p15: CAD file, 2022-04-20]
STL/Aux Top - Sega Genesis - Multitap.STL
72.9 x 7.96 x 67.0

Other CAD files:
STL/Aux Top - Nintendo NES Classic.STL
STL/Aux Bottom - Phillips CD-i.STL
STL/Aux Top - Phillips CD-i.STL
STL/Aux Bottom - Sega Genesis-Megadrive Multitap.STL
STL/Aux Bottom - 1 Player.STL
STL/Aux Bottom - 2 Player.STL
STL/Aux Bottom - 4 Player.STL
STL/Aux Bottom - Panasonic 3DO.STL
STL/Aux Top - Atari 2600.STL
STL/Aux Top - Atari 7800.STL
STL/Aux Top - Atari Jaguar.STL
STL/Aux Top - NEC PC-FX.STL
STL/Aux Top - NEC PCEngine.STL
STL/Aux Top - NEC TurboGrafx-16.STL
STL/Aux Top - Nintendo 64.STL
STL/Aux Top - Nintendo Famicom.STL
STL/Aux Top - Nintendo Gamecube.STL
STL/Aux Top - Nintendo NES.STL
STL/Aux Top - Nintendo SFC.STL
STL/Aux Top - Nintendo SNES.STL
STL/Aux Top - Nintendo Virtual Boy.STL
STL/Aux Top - Panasonic 3DO.STL
STL/Aux Top - SNK Neo Geo.STL
STL/Aux Top - Sega Dreamcast.STL
STL/Aux Top - Sega Genesis.STL
STL/Aux Top - Sega Master System.STL
STL/Aux Top - Sega Megadrive.STL
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

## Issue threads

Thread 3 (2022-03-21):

Main Gerber file pin spacing

pceslayer, 2022-03-21:
Not sure this is because of the ESP32 boards I have on hand or because of how the PCB was printed, but my ESP32's pins do not line up with the PCB through holes. I have two different ESP32 models and they both have the same issue. I used OSH Park to print the PCB's and never had an issue with them before.

I have a different version of the DevKitC on the way from DigiKey. Hopefully it'll fit.

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

pmgducati, 2022-03-21:
I used a NodeMCU-32 , the only difference is the lack of silkscreen pin callout on the top, which apparently makes it slightly thinner.

I have purchased them from both places below and used them in multiple blue retro builds:

https://www.cytron.io/p-nodemcu-32s-wifi-bluetooth-ble-iot-dev-board

https://www.amazon.com/HiLetgo-ESP-WROOM-32-Development-Microcontroller-Integrated/dp/B0718T232Z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

pmgducati, 2022-03-21:
The BOM has been updated with the Amazon link,

pceslayer, 2022-03-23:
Hi i'm attempting to edit the main board file in eagle to adjust the spacing and I'm missing the ESP32-DevKitC library.
Could you point me in the right direction? Thanks!

joeybaumgartner, 2022-09-25:
Just a note that I think the manufacturer changed the layout of the board linked in the BOM. I ordered one linked by the BOM and it does not fit the pinouts of the circuit board. I ended up ordering these and they work: https://www.amazon.ca/gp/product/B07QCP2451/.

**NOTE**: These boards will not program unless you hold down the `IO0` button on the board itself when programming over USB. Updating firmware via the OTA interface appears to work just fine.

Closed 2022-03-23.

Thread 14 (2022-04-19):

Phillips CD-i PCB

pmgducati, 2022-04-19:
I do not have this system this PCB is compatible with, please put your findings here.

hipsofjw, 2022-06-14:
I'm a little confused about this PCB. What are the extra 4 holes for? They don't seem to fit a typical CD-i port. Also, I think you only need one cable since it has the same connector on each end.

pmgducati, 2022-06-14:
Hi, I am assuming you are referring to these holes:

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

That is for a USB mini connector, according to DarthCloud you need external power for the BlueRetro setup.  The sole purpose of that is to power the unit.

Here is the link to the comments:
https://github.com/darthcloud/BlueRetro/wiki/BlueRetro-Cables-Build-Instructions#cd-i-adapter-cable

pmgducati, 2022-06-14:
I should add a callout on the PCB for that.  I will get it in the next revision.

pmgducati, 2022-06-14:
Missed if there too!  Thanks for catching it.  I will update both the PCB and BOM

hipsofjw, 2022-06-14:
One more thing while I've got you. There's one pad each for RTS and RXD for each port, but there are two RTS and RXD pins in each connector. Do I need to solder both to each pad?

pmgducati, 2022-06-14:
I don't believe so, it looks like all you need it P1 RTS/RXD from the front and P2 RTS/RXD from the Rear.  Check out the schematic from Darth's repo

https://github.com/darthcloud/BlueRetroHW/blob/master/DIY/CDI.pdf

pmgducati, 2022-06-14:
Also I updated the CD-i PCB but realized that the library I used had a obsolete part for the mini USB port.  I updated and the foot print did change.  When you buy one for your PCB with the old foot print just make sure to measure the distance from the front row of pins to the GND legs.  the pinout is standard and should fit whatever you find.  Im looking forward to hearing your about your findings on the PCB

hipsofjw, 2022-06-15:
Went sent the new gerber off to be printed. I'm in China, so it's only a couple of bucks. I'll let you know how it works once I set it up.

Thanks for quick responses and updates!

hipsofjw, 2022-06-15:
One additional thing: how are you supposed to plug in the micro USB while the PCB is in its case?

pmgducati, 2022-06-15:
Hey,
I completely missed that when modeling the housing.  I updated it by adding the cutout for power and offsetting the controller cable hole to the side.

I just pushed the commit that includes the changes.

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

hipsofjw, 2022-06-15:
That was fast! No need for a second wiring hole for P2?

pmgducati, 2022-06-15:
I mirrored the hole for P2:

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

Let me know what you think, you're the expert here ;)

pmgducati, 2022-06-15:
I pushed it to a branch here:
https://github.com/pmgducati/Blue-Retro-AIO-Units/tree/CD-i-housing-P2-Update

Here is the model if you want to look at it:
https://github.com/pmgducati/Blue-Retro-AIO-Units/blob/CD-i-housing-P2-Update/STL/Aux%20Bottom%20CD-i.STL

if it looks good I will merge it.

hipsofjw, 2022-06-15:
Looks good to me. Thanks for the update! I'll get one printed up soon.

pmgducati, 2022-06-15:
Merged!

pmgducati, 2022-09-28:
@hipsofjw did you finish this?  How is it working?

Nekimaliizgrada, 2022-11-19:
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

That's it

Nekimaliizgrada, 2022-11-19:
Phillip ate and drank what his brothers ate and drank. The disrespect of some people. Come on guys.

pmgducati, 2022-11-19:
@Nekimaliizgrada context?

Nekimaliizgrada, 2022-11-19:
Climax 😂😂😂😂Sent from my iPhoneOn Nov 19, 2022, at 2:00 PM, pmgducati ***@***.***> wrote:
@Nekimaliizgrada context?

—Reply to this email directly, view it on GitHub, or unsubscribe.You are receiving this because you were mentioned.Message ID: ***@***.***>

Closed 2022-12-20.

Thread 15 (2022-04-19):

PC-FX PCB

pmgducati, 2022-04-19:
I do not have this system this PCB is compatible with, please put your findings here.

hipsofjw, 2022-06-14:
I built one of these. Made the controller connectors with some housings I 3D-printed from thingaverse. Used a SNES cable and glued the connectors into the housing. Haven't tried two-player yet, but I did mess around with whatever fighting game I had and it works great!

hipsofjw, 2022-06-14:
I managed to pair both an Xbox Series X controller and a PS4 controller and it works! Nice!

This did lead me to a question though. To pair a second controller, one must enter inquiry mode with the first controller already paired. To enter inquiry mode, you press the BOOT button on the ESP32 itself. In order to do that, you need to take the main board out of its case. Is that right?

Closed 2022-06-14.

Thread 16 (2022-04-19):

NeoGeo/SuperGun/JAMMA PCB

pmgducati, 2022-04-19:
I do not have this system this PCB is compatible with, please put your findings here.

pmgducati, 2022-12-28:
I recently picked up a Neo Geo and was able to successfully test this variant.  Closing this issue as functionality has been verified
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

Closed 2022-12-28.

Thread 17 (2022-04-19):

SNES(NTSC)/(PAL)/Super Famicom PCB

pmgducati, 2022-04-19:
I do not have this system this PCB is compatible with, please put your findings here.

amaiorano, 2022-10-24:
So far this works perfectly for 2 players, with only 2 level shifters. I wanted it to work for 4 players, but the SNES extensions I got from AliExpress are missing 2 wires -- this is mentioned on [the last bullet point of the official instructions](https://github.com/darthcloud/BlueRetro/wiki/BlueRetro-Cables-Build-Instructions#bill-of-materials-11).

Here's what it currently looks like:

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

I'm currently waiting on a lot of broken original SFC controllers that I can harvest the cables from so that they have the 7 wires all connected, and will test that multitap support works. I'll report my findings here.

pmgducati, 2022-10-25:
This is great to hear, looking forward to your updates.

RetroBobba, 2022-11-16:
I've made a full populated board with resistors for the PAL console and tried Micro Machines with 4 Players. It works fine :-)

Thanks for your work

pmgducati, 2022-11-16:
Thats Great to hear, thanks for the update!

Closed 2022-11-16.

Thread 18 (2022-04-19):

Sega Dreamcast PCB

pmgducati, 2022-04-19:
I do not have this system this PCB is compatible with, please put your findings here.

joeybaumgartner, 2022-09-11:
I'm doing a build of this and hope to fully test this soon. Not sure if this is due to routing or not, but the P1 through P4 solder points are reversed compared to all of the other 4 player units I've assembled so far (N64 and GC). This just makes it so that the cables running out the 3D printed case cross over each other and harder to tighten up. I've just run the wires out straight and made a note to myself that P4 = P1, P3 = P2, P2 = P3, and P1 = P4.  Not sure if it's easer to update the PCB, or make an alternate box to 3D print.

pmgducati, 2022-09-12:
Hey,
Thanks for the heads up, I must have missed that when making the PCB.  I have made the changes and the pads now match the others and housing.
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

pmgducati, 2022-09-12:
Keep me updated on how your project goes!

corim123, 2022-09-24:
I'm working on some of the GC adapters(well waiting on DB25s) and plan on getting some of these boards next as I've got a Dreamcast kicking around somewhere.

joeybaumgartner, 2022-09-25:
Sorry for such a late reply on this. Still working with the original boards (ordered them before noticing the issue). I have had some success where I can connect a controller up to the Dreamcast, but cannot get it to recognize the Start button on either an XBox One controller or with a Wii-mote connected to a SNES Classic controller.

@corim123 I have had no issues with the GC adapters so far, and I used the Wii-mote + SNES Classic controller for playing GBA games via GB Player and that's 1000 times better than using a GC controller.

pmgducati, 2022-09-28:
I just picked up a dreamcast and ordered the PCBs myself.  I will update when the PCBs arrive in a couple weeks

joeybaumgartner, 2022-09-28:
That sounds great! I'm interested to hear your results.

pmgducati, 2022-11-28:
@joeybaumgartner Finally got the PCBs assembled and my Dreamcast setup and I am not having any issues with my setup.  I have tested with 3 different 8bitdo controllers (SN30 Pro+, Pro 2 and N30), 2x PS4 controllers and 2x Xbox One controllers.  I played for about 4 hours with different combinations of all my controllers and single and multiplayer.  I tested Sonic adventure, zero gunner 2, MVC2, DOA 2, Mr Driller, Hydro Thunder and Daytona USA.

I am going to close this comment as I am not seeing any issues with so many games.  I you are still have issues please open a new issue.
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

Closed 2022-11-28.

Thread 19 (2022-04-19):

Virtual Boy PCB

pmgducati, 2022-04-19:
A Controller cable needs to be sourced to test this PCB

pmgducati, 2022-12-21:
I have found a 3D printable model of the male end of the controller adapter ( Thanks to RetroOnyx).  The Housing has been updated to allow for the power switch and barrel plug, and the BOM is updated.  I ordered the PCB and Housing parts with an ETA of 1/13/23.

pmgducati, 2023-01-13:
I assembled the PCB, no buttons work. the only reaction that I get is right on the Dpad resets the Virtual Boy.  I am parking this PCB unless there is further interest in it.

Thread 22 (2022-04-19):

JVS PCB and Housing Cover

pmgducati, 2022-04-19:
Design PCB to fit within the form factor of the project and find Logo to use for Aux Top Variant CAD

pmgducati, 2022-04-20:
Started working on the Schematic and there are some trace name issues that need to be cleared on with the blueretro project before proceeding further

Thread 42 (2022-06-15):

Sega Genesis/Megadrive Multitap PCB

pmgducati, 2022-06-15:
I do not have this system this PCB is compatible with, please put your findings here.

DariensArcade, 2022-06-19:
Working:  Fully populated Multitap board working in 2 player mode in both 3/6 buttons (BR Setting Gamepad / Gamepad Alt.  respectively) on Genesis Model 1, 2, and 3.

Further testing needed: I'm getting glitches attempting to use multi-tap modes but probably due to my controllers. i.e. Out of control scrolling with NHL '95 (EA Multi-tap. BR setting "alt")

Will test further with other controllers/games/tap types

Reporting since no one else has.

pmgducati, 2022-07-01:
This is great to hear,  is NHL95 the only game you are seeing issues with?  Also is it on an original cart/flashcart?

Closed 2022-09-12.

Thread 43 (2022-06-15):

PSX PCB

pmgducati, 2022-06-15:
I have successfully tested this with a PS2, but I do not have PSX, please put your findings here.

badamsz, 2022-07-18:
I have tested on PSX/PSone and it works as long as you connect PIN 3 (7.6v) as PIN 5 (3.5v) provides insufficient power and the ESP won't boot all the way up.

pmgducati, 2022-09-12:
Thanks for the feedback, I have noted this on the silkscreen of the new rev of the PCB

Closed 2022-09-12.

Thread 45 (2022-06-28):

Using Ps2 adaptor on an original Xbox

Harryunderhill, 2022-06-28:
Hi All

Ive made an PS2 PSX adaptor which works great on both my PSX/PS2, how ever when I try
To use it on my original Xbox with my PS2 to Xbox adaptor, it powers up but nothing, it don’t sync the controller.

Ive been using the xbox to PS2 adaptor on my Xbox for years and it works great with a wired PSX controller and  I just want To use my wiresless adaptor on it ?

I done the pin swap fix for the PS2 adaptor, which works great on my PS2 PSX.

any help would be great.

pmgducati, 2022-06-29:
It sounds like you are not getting enough power for the ESP to work correctly.   What Pad are you using for the PSX/PS2? (8V or 3V3?)  My Guess is that the xbox adapter wants to use the opposite that you are using and the LED is getting enough power to light up the the ESP is stuck in a boot loop due to the lack of consistent power.

Harryunderhill, 2022-06-29:
> It sounds like you are not getting enough power for the ESP to work correctly. What Pad are you using for the PSX/PS2? (8V or 3V3?) My Guess is that the xbox adapter wants to use the opposite that you are using and the LED is getting enough power to light up the the ESP is stuck in a boot loop due to the lack of consistent power.

I’m using 3V3

pmgducati, 2022-06-29:
you could try to swap to the 8V pin to see if it works with the xbox adapter.

Harryunderhill, 2022-06-29:
Hi there I swapped the pins over to 8v and still nothing, I then tried both Xbox one and PS4 controller, don’t sync.
As soon as I plug the adaptor into the PS2 and turn both the PS4 and the Xbox one controller on they sync straight away.

any other ideas ?

pmgducati, 2022-07-01:
Is the adapter that you use still available?  I could pick one up and do some testing.

For now, if you could remove the power connection (8v/3V3) from the controller side and use USB to power the ESP.  If it works with the adapter this will narrow it to a power delivery issue.

Harryunderhill, 2022-07-01:
> Is the adapter that you use still available? I could pick one up and do some testing.
>
> For now, if you could remove the power connection (8v/3V3) from the controller side and use USB to power the ESP. If it works with the adapter this will narrow it to a power delivery issue.

Ive disconnected the power and powered the ESP externally and the controller syncs, however none of the buttons works or you can't navigate around the Xbox screen.

There is no brand on the adaptor either so don't no if you can still buy it.

xybots2022, 2022-07-10:
Hi I have exactly the same problem i bought a forcebox psx to xbox convertor and tried that with the ESP32 and I get exactly the same problem as Harry, ive tried powering the esp32 separately and the controller syncs but I cant navigate round the screen, any help would be great.

pmgducati, 2022-07-11:
@xybots2022 can you post a link to the adapter that you are using?  I will pick one up and do some testing.

xybots2022, 2022-07-25:
All I Do is search psx to xbox adaptors in eBay and I bought a couple from there which both work wired on the xbox but not with bluetooth.

thanks

pmgducati, 2022-11-14:
Without a specific unit to test against I will not be able to work on this issue

Closed 2022-11-14.

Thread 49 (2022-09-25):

PIN Spacing Issue

joeybaumgartner, 2022-09-25:
Just a note that I think the manufacturer changed the layout of the board linked in the BOM. I ordered one linked by the BOM and it does not fit the pinouts of the circuit board. I ended up ordering these and they work: https://www.amazon.ca/gp/product/B07QCP2451/.

**NOTE**: These boards will not program unless you hold down the `IO0` button on the board itself when programming over USB. Updating firmware via the OTA interface appears to work just fine.

joeybaumgartner, 2022-11-14:
This is the link for the "corrected" version that would fit on the PCB. I did find this version did have an issue with flashing (I had to hold a button down on the unit), but otherwise this fit the pin-spacing. This is on Amazon Canada, rather than Amazon US, but the description for the one I got with wide spacing matched what was in the BOM. But I'm wondering if the seller had multiple versions.

pmgducati, 2022-11-29:
I eliminated the thinner version and went with the standard ESP32 footprint this should eliminate confusion in the future

Closed 2022-11-29.

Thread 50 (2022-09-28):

Filament printing?

amaiorano, 2022-09-28:
Hi there!

First of all, awesome project! Thank you for making these, and offering them up for free!

I am interested in making the SNES adapter. I don't have a ton of experience with 3D printing, but when looking at the screenshots of your prints, I get the impression that these STLs won't print all that well with a filament printer. Am I correct? If so, would it be possible to create a simple 1 and 2 hole shell with a generic cover that could be easily printed with a filament printer?

Thanks!

pmgducati, 2022-09-28:
I have had a few people use my housings on FDM printers, here is an example of one:

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

I don't think you would have issues printing them.

Closed 2022-09-29.

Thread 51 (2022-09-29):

DB25 male/female is inverse of official BlueRetro DIY instructions

amaiorano, 2022-09-29:
Hello,

I noticed that the choice of male or female DB25 connector is the inverse of what is specified on the official BlueRetro's site for DIY. For example, for the ESP32 module, [it says to use a female connector solder cup](https://github.com/darthcloud/BlueRetro/wiki/BlueRetro-DIY-Build-Instructions#bill-of-materials), while your project uses a male one. Of course, the opposite is true for the cable adapters.

I know it's not a big deal, as one can simply swap the male/female DB25 connector as needed, but it might be worth mentioning somewhere in the README, especially for those of us (me) that have already built the official DIY ESP32 module, and would like to try interfacing it with a PCB-based one from this site.

Thank you for this awesome project!

P.S. Unrelated, but I think it would be nice if the README also included a screenshots showing the PCBs wired up _inside_ the 3D-printed shells, with the cover off, so that we can see how well it fits inside. Probably also worth mentioning that the cables would need to be threaded through the case before soldering to the PCB.

pmgducati, 2022-09-29:
This was an intentional design choice that I made. I would prefer to minimize pins that can be bent/damaged.  which is why I swapped the female/male.  I created a matching version of the ESP side with the male pins to go with all the systems.  The idea is that you would build the complete solution from here.

This started as a personal project that I wanted to make for myself and throughout the development I had a few people ask me to post what I made/make additional systems.

If you want to submit instructions, I will be happy to include them.

amaiorano, 2022-09-29:
Makes sense, and thank you for sharing!

Closed 2022-09-29.

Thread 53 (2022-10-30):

BOM - Main PCB (ALT WIDE VERSION) - Wrong 1965-ESP32-DEVKITM-1-ND Partno / Link

stefanpausch, 2022-10-30:
The linked 1965-ESP32-DEVKITM-1-ND is a 34 Pinout version instead of a required 38 Pinout Version.

Linked is a ESP32 Mini-1

Guess this is the same issue as #49

pmgducati, 2022-11-14:
The Link has been update.

https://github.com/pmgducati/Blue-Retro-AIO-Units/pull/56

Closed 2022-11-14.

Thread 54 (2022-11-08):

Main PCB _ No Soldermask on anchor / GND point of connector

stefanpausch, 2022-11-08:
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

Why is the solder mask missing around the anchor points of the connector?

pmgducati, 2022-11-14:
This is resolved here: https://github.com/pmgducati/Blue-Retro-AIO-Units/pull/55

Closed 2022-11-14.

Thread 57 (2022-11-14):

Wii Ext & NES/SNES Mini PCB Design

pmgducati, 2022-11-14:
Initial design is complete and awaiting PCBs for testing.

Progress can be seen here:
https://github.com/pmgducati/Blue-Retro-AIO-Units/tree/Wii-Ext-NES-SNES-Mini

pmgducati, 2022-11-28:
Got the PCBs today and assembled them.  The worked as intended with the SNES Mini, NES Mini and Wii.
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

pmgducati, 2022-11-29:
Awaiting new PCB as I added 5.1k pulldown resistors to the CC1 and CC2  pins on the USB-C plug to allow the use of a PD charger to negotiate 5V.  I also laid out the PCB again and spread the pads and resistors for ease of assembly.

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

pmgducati, 2022-12-28:
The new PCB arrived and the testing was successfully with a UBC-C PD Power Adapter and Normal Power Adapter.  I am closing this as the PCB design is complete

Closed 2022-12-28.

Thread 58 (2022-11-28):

Wii Ext, SNES/NES Mini Housing Design

pmgducati, 2022-11-28:
Now that the PCB has tested successfully and no changes are needed, I will start working on the Housing CAD.

pmgducati, 2022-11-29:
Per https://github.com/pmgducati/Blue-Retro-AIO-Units/commit/540e3a828a736565fab97cc6a5ce2194736ba0d8

I have completed the preliminary CAD for the Wii EXT & NES/SNES Classic PCBs.  I have ordered them from Shapeways (ETA 1/6/23) and will merge the branch if no additional changes are needed.

Included in this commit are the following:
Updated CAD and STLs for the AUX housing Top for the NES Classic, SNES Classic, Famicom Classic, Super Famicom Classic, Wii Ext and Optional Wii

The Aux Bottom that covers all the variants mentioned above.

As Always the CAD is included and the new font for the Wii Variants is included as well.

See Below for R1 Renders:
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

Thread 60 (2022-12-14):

NTSC NES Only A Button Working

hydrohs, 2022-12-14:
I just wired up the NES and SNES PCBs, but I’m having an issue with my NES version. I can connect controllers but the A button is the only input I get. I double checked continuity following the schematics and everything is connected correctly, I’m not sure what else to check.

hydrohs, 2022-12-14:
@pmgducati I’m tried with an NSO NES controller, NSO SNES controller, and a Dualshock 4

pmgducati, 2022-12-15:
PCB Looks good, Can you verify the pinout for the pigtails?
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

hydrohs, 2022-12-15:
That’s correct, yes. If it’s at all relevant my console is RGB modded, and I’m using an Everdrive.

hydrohs, 2022-12-20:
I think I found the issue, I'm almost positive one or both of my buffer chips were bad. I have no way to test them for sure, but I probably killed them with too much heat or something. I swapped them onto my SNES PCB (which was working) which then no longer worked. Ended up just assembling another from scratch and it's working perfectly. Your help and this project are much appreciated.

Closed 2022-12-20.

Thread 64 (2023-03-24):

PCEngine 6 buttons

tawyy, 2023-03-24:
Hello,

I've made some of your PCB since it is exactly what I needed :) Thank you for everything !
I have tried Neo Geo and PCEngine so far. I need more cables for other systems, but i will soon. I could help you for issue 41, I have a RGB modded famicom AV which is my main famicom console for playing, and a NES PAL, my own NES from childhood....

So, I tried to play street fighter with your adapter and it works fine when playing with 2 buttons mode, but on 6 buttons mode > GameAlt, the controllers are not :( The controller is connected as 2nd player and can also control the first one where the bottom button seems to be always pressed in.  Am I missing something ?

Thank you

pmgducati, 2023-03-24:
Hi,
Any testing that you can do with the Famicom and NES PAL would be AWESOME!  Put your findings in the issue.

As far as the 6 button issue goes,  I will do some testing this weekend to see if I can replicate the issue.  Just for reference, what controllers are you using?  Also can you post a picture of the PCB for PCE?

Thanks!

tawyy, 2023-03-24:
I found a solution to the 6 button problem... It seems weird at first, but I tried connecting the shield to ground and it solved all my problems! I read this on a HumbleBazooka thread somewhere... Not sure why it might affect 6 button mode, but it does!
I will try the PAL NES and my Japanese Famicom AV when I have the connectors.
Thank you.

pmgducati, 2023-03-24:
This is great to hear, I will test it as is (no shield to gnd) and the  your finding with my setup.  I will update the issue and make and needed changes for the PCB and call outs.

Thanks for digging in!

pmgducati, 2023-03-25:
I did some testing with and without the shield to GND and can verify this also.  I have added a callout on the silkscreen for the PCB.  It reads "Connect the Cable Shield to GND"

https://github.com/pmgducati/Blue-Retro-AIO-Units/pull/65

Closed 2023-03-25.

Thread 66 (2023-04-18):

PCE 6 buttons

reggieleelee31, 2023-04-18:
Hi

I am happy you share a pcb to make it easy to build.  I have a problem to setup PCE 6 buttons controller.  I have using switch pro controller for source and destination set to pce 6 botton and save.  It is showing saved but it is not work.  That I go back to config page.  It is showing default in mapping.  Do you know how to set it?  I am flashing 1.8.3 universal firmware.

Thanks

Closed 2023-04-20.

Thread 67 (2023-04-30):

PSX/PS2 PCB has incorrectly numbered vias for L connector

amaiorano, 2023-04-30:
It looks like the numbering for the L connector vias on the PSX/PS2 PCB is flipped horizontally:

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

I was following the traces to make sure I connected my wires right, and was confused that the pad numbers didn't match up with the DB25 pin numbers as per darthcloud's schematic.

pmgducati, 2023-05-03:
The pin numbers are different, I swapped the male and female DB25 connectors so that the female version is on all the system adapters,  That way there is only male connector that could get bent pins and have to be repaired.  With the swap, the pin numbers are reversed on all the PCBs.  The traces all go to the correct pins on the main board and has been tested and verified to work as intended.

Closing this comment.

amaiorano, 2023-05-03:
> The pin numbers are different, I swapped the male and female DB25 connectors so that the female version is on all the system adapters, That way there is only male connector that could get bent pins and have to be repaired. With the swap, the pin numbers are reversed on all the PCBs. The traces all go to the correct pins on the main board and has been tested and verified to work as intended.

Ah, I see, that makes sense. It's a bit unfortunate because the numbering of the pads on the silkscreen match up with what's in the official schematics, but not the DB25 pin numbers. Anyway, it does indeed work as expected. Thanks.

Closed 2023-05-03.

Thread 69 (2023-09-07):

No an issue with the hardware just a question

brendan1495, 2023-09-07:
Maybe a daft question but what does

OD & PP stand for, looking at the neogeo , supergun, jamma adapter

Thanks

pmgducati, 2023-09-07:
Short answer is that OD is the one you need.

Darthcloud has OD (Open Drain) and PP (Push Pull) for Neo Geo and the 2600/SMS versions.

Here is the explanation from his repo:

Typical parallel input system simply use a switch between input line and GND which pull it low on button press. The input line idle high via a pull-up resistor in the console. To best emulate this behavior use the open drain schematic.

If for a specific application you need the line to be actively be driven high you can follow the Push-Pull variant.

I made both to provide a complete collection of cables. I have the OD version for my Neo Geo and it works great.  I'm working on a internal version also.

brendan1495, 2023-09-07:
Thanks a lot for the explanation, I will get the OD version sent off for manufacture, look forward to the internal.

Again thanks

Closed 2023-11-24.

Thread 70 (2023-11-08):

Blog post on making BlueRetro AIO units

amaiorano, 2023-11-08:
Hi, I didn't know how else to reach you, so I hope it's okay that I create an issue for this. I'm a big fan of this project, and I wrote a blog post all about how I made a bunch of these units for different systems. I thought you might enjoy it:

https://amaiorano.io/2023/11/06/blueretro-aio.html

pmgducati, 2023-11-13:
Thanks for taking time to build and review the adapters.  Do you mind if I put the link on the repo's readme?

amaiorano, 2023-11-13:
> Thanks for taking time to build and review the adapters. Do you mind if I put the link on the repo's readme?

I would be honored!

pmgducati, 2023-11-28:
Posted in the Readme.md

amaiorano, 2023-11-28:
Thanks!

Closed 2023-11-28.

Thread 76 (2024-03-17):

Open sch and brd

retrolover, 2024-03-17:
Hi, thanks by hard work you made.

I have some issues to open schematics or boards with Eagle, it trhows me : file not supported error.

Are urs designed made with eagle right?

pmgducati, 2024-03-17:
Yes, I used eagle to create the PCBs.  I have not run into a file unsupported error when opening my own or any others, sometimes GitHub adds a header to the files if you download them individually, try downloading the repo as a zip and see if that helps.

retrolover, 2024-03-17:
Thanks i Will try It.
For NeoGeo IS necessary level shifter?

Regars
Israel

El dom, 17 mar 2024 13:02, pmgducati ***@***.***> escribió:

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

pmgducati, 2024-03-17:
Yes, any parts listed in the BOM are required.

One other note use the OD version.  The PP version is for non standard use cases.

retrolover, 2024-03-17:
Gotcha.
Then for neogeo i must use level shifter.

El dom, 17 mar 2024 14:43, pmgducati ***@***.***> escribió:

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

Closed 2025-03-03.

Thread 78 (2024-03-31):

ESP 32

brendan1495, 2024-03-31:
Not really an issue but would the "ESP32-DevKit C development board WIFI Bluetooth development board 38Pin TYPE-C interface equipped with ESP32-D0WD chip" work with this I have already bought a couple the first was to narrow and the second not enough pins, Any help would be appreciated thanks

the ones I am looking at are:

https://www.aliexpress.com/item/1005006500102606.html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

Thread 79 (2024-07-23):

Genesis Multitap Issues/Phantom Inputs

ca7bc0c5f2, 2024-07-23:
An extension of https://github.com/darthcloud/BlueRetro/issues/1041.

I’ve had challenges using multitaps on Madden 95 and NBA Jam running on MegaSD. Clipping chip legs and extensively cleaning pcb of flux after soldering seems to have helped to a degree. Mega Bomberman has been the best multitap game I’ve tried. Happy to have an extensive dialog to get this reliably working.

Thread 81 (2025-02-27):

PSX/PS1 build question

BuzzBuzzards, 2025-02-27:
Hi there!

I want to build an adapter to use my BlueRetro with PS1/PS2 consoles. Right now I have an AliExpress BlueRetro Core (that one with acrylic shell). I noticed that darthcloud uses lots of resistors and diodes for his variant of DIY cable, but I can see neither of those components on your PCB. Can you share why did you ended up not using any of those parts (besides components shortage mentioned in[ this issue](https://github.com/darthcloud/BlueRetro/issues/225))? I want to make my build as cheap as possible so I'm thinking about how is it save to omit those components.

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

BuzzBuzzards, 2025-02-27:
Nevermind, should have investigated a bit further. Darthcloud used those as a preventive measure from random inputs, as it was stated [there](https://github.com/darthcloud/BlueRetro/issues/102#issuecomment-1831116340).

Closed 2025-02-27.

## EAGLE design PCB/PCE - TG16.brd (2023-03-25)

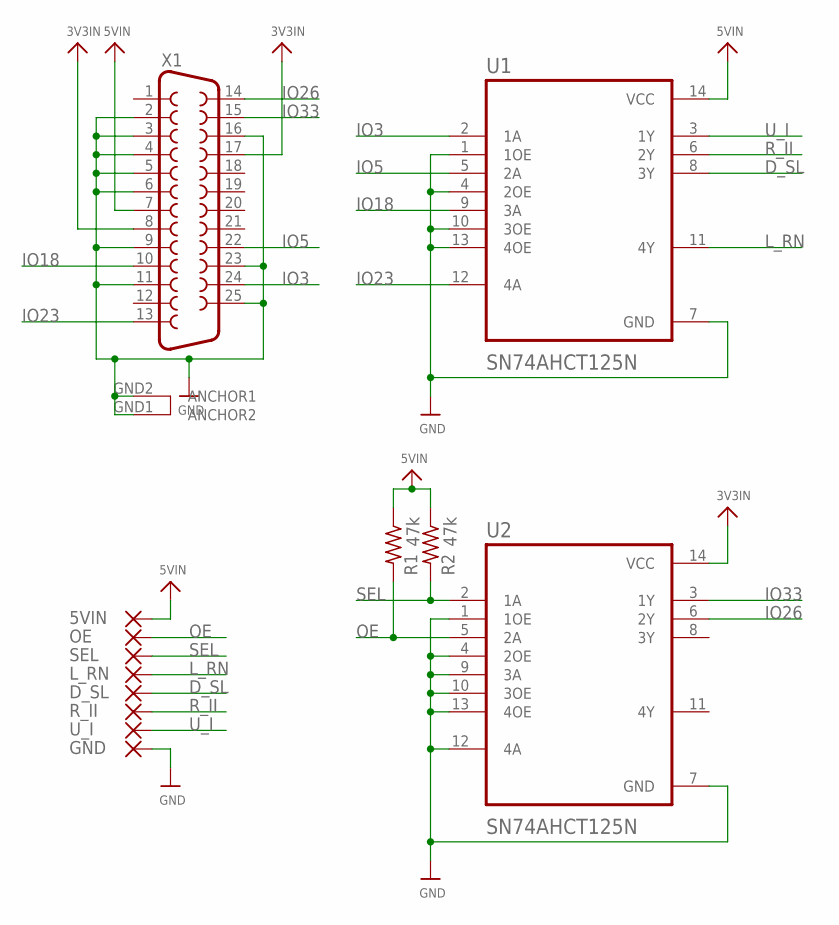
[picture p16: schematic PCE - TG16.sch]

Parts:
5VIN: SMD5; SMD2,54-5,08
D_SL: SMD5; SMD2,54-5,08
GND: SMD5; SMD2,54-5,08
L_RN: SMD5; SMD2,54-5,08
OE: SMD5; SMD2,54-5,08
R1, R2: 47k; R1206
R_II: SMD5; SMD2,54-5,08
SEL: SMD5; SMD2,54-5,08
U1, U2: SN74AHCT125N; DIP794W45P254L1969H508Q14
U_I: SMD5; SMD2,54-5,08
X1: DB25_FEMALEHP; F25HP

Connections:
3V3IN: U2.14 (VCC), X1.8, X1.17
5VIN: 5VIN.1, R1.1, R2.1, U1.14 (VCC), X1.7
D_SL: D_SL.1, U1.8 (3Y)
GND: GND.1, U1.1 (1OE), U1.4 (2OE), U1.7 (GND), U1.10 (3OE), U1.13 (4OE), U2.1 (1OE), U2.4 (2OE), U2.7 (GND), U2.9 (3A), U2.10 (3OE), U2.12 (4A), U2.13 (4OE), X1.2, X1.3, X1.4, X1.5, X1.6, X1.9, X1.11, X1.16, X1.23, X1.25, X1.GND1 (ANCHOR2), X1.GND2 (ANCHOR1)
IO3: U1.2 (1A), X1.24
IO5: U1.5 (2A), X1.22
IO18: U1.9 (3A), X1.10
IO23: U1.12 (4A), X1.13
IO26: U2.6 (2Y), X1.14
IO33: U2.3 (1Y), X1.15
L_RN: L_RN.1, U1.11 (4Y)
OE: OE.1, R1.2, U2.5 (2A)
R_II: R_II.1, U1.6 (2Y)
SEL: R2.2, SEL.1, U2.2 (1A)
U_I: U1.3 (1Y), U_I.1

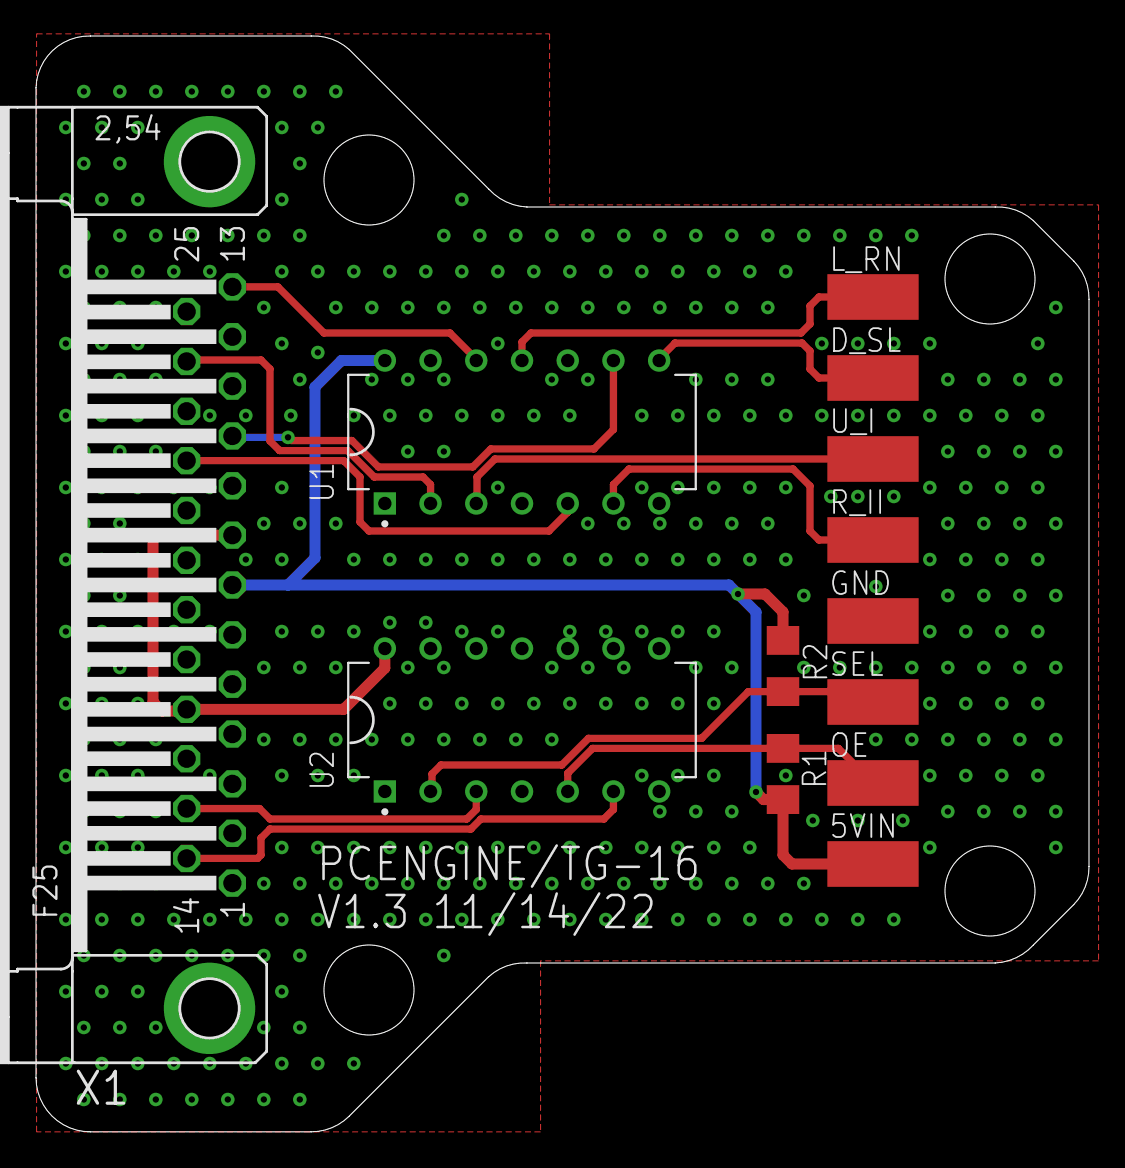
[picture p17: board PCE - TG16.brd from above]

Board: 2 copper layers, 58.5 x 60.9 mm, 13 parts (0 on the bottom side), 15 nets.

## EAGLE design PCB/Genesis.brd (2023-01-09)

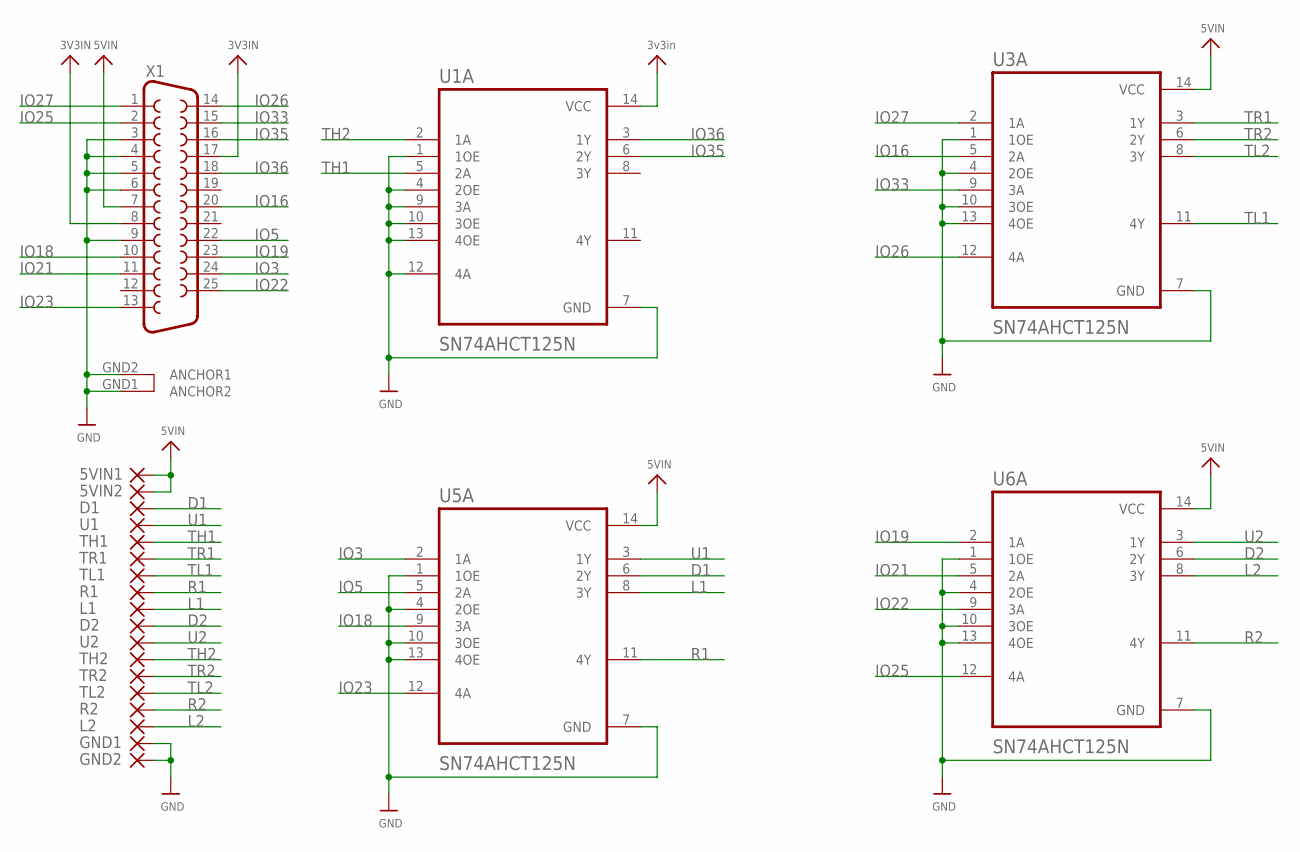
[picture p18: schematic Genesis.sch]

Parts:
5VIN1, 5VIN2: SMD5; SMD2,54-5,08
D1, D2: SMD5; SMD2,54-5,08
GND1, GND2: SMD5; SMD2,54-5,08
L1, L2: SMD5; SMD2,54-5,08
R1, R2: SMD5; SMD2,54-5,08
TH1, TH2: SMD5; SMD2,54-5,08
TL1, TL2: SMD5; SMD2,54-5,08
TR1, TR2: SMD5; SMD2,54-5,08
U1, U2: SMD5; SMD2,54-5,08
U1A, U3A, U5A, U6A: SN74AHCT125N; DIP794W45P254L1969H508Q14
X1: DB25_FEMALEHP; F25HP

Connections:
3V3IN: U1A.14 (VCC), X1.8, X1.17
5VIN: 5VIN1.1, 5VIN2.1, U3A.14 (VCC), U5A.14 (VCC), U6A.14 (VCC), X1.7
D1: D1.1, U5A.6 (2Y)
D2: D2.1, U6A.6 (2Y)
GND: GND1.1, GND2.1, U1A.1 (1OE), U1A.4 (2OE), U1A.7 (GND), U1A.9 (3A), U1A.10 (3OE), U1A.12 (4A), U1A.13 (4OE), U3A.1 (1OE), U3A.4 (2OE), U3A.7 (GND), U3A.10 (3OE), U3A.13 (4OE), U5A.1 (1OE), U5A.4 (2OE), U5A.7 (GND), U5A.10 (3OE), U5A.13 (4OE), U6A.1 (1OE), U6A.4 (2OE), U6A.7 (GND), U6A.10 (3OE), U6A.13 (4OE), X1.3, X1.4, X1.5, X1.6, X1.9, X1.GND1 (ANCHOR2), X1.GND2 (ANCHOR1)
IO3: U5A.2 (1A), X1.24
IO5: U5A.5 (2A), X1.22
IO16: U3A.5 (2A), X1.20
IO18: U5A.9 (3A), X1.10
IO19: U6A.2 (1A), X1.23
IO21: U6A.5 (2A), X1.11
IO22: U6A.9 (3A), X1.25
IO23: U5A.12 (4A), X1.13
IO25: U6A.12 (4A), X1.2
IO26: U3A.12 (4A), X1.14
IO27: U3A.2 (1A), X1.1
IO33: U3A.9 (3A), X1.15
IO35: U1A.6 (2Y), X1.16
IO36: U1A.3 (1Y), X1.18
L1: L1.1, U5A.8 (3Y)
L2: L2.1, U6A.8 (3Y)
R1: R1.1, U5A.11 (4Y)
R2: R2.1, U6A.11 (4Y)
TH1: TH1.1, U1A.5 (2A)
TH2: TH2.1, U1A.2 (1A)
TL1: TL1.1, U3A.11 (4Y)
TL2: TL2.1, U3A.8 (3Y)
TR1: TR1.1, U3A.3 (1Y)
TR2: TR2.1, U3A.6 (2Y)
U1: U1.1, U5A.3 (1Y)
U2: U2.1, U6A.3 (1Y)

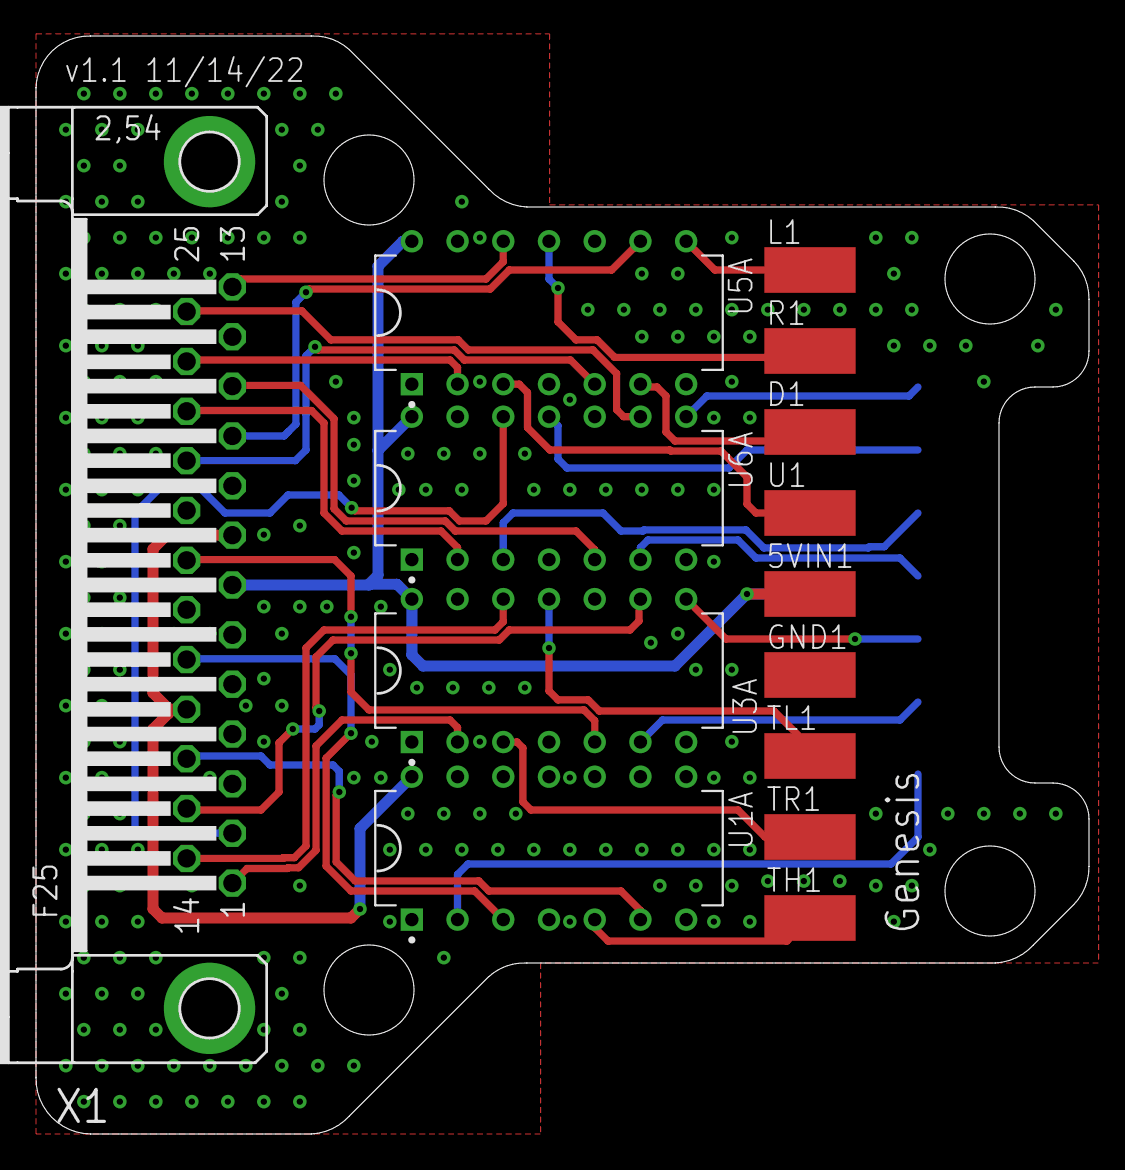
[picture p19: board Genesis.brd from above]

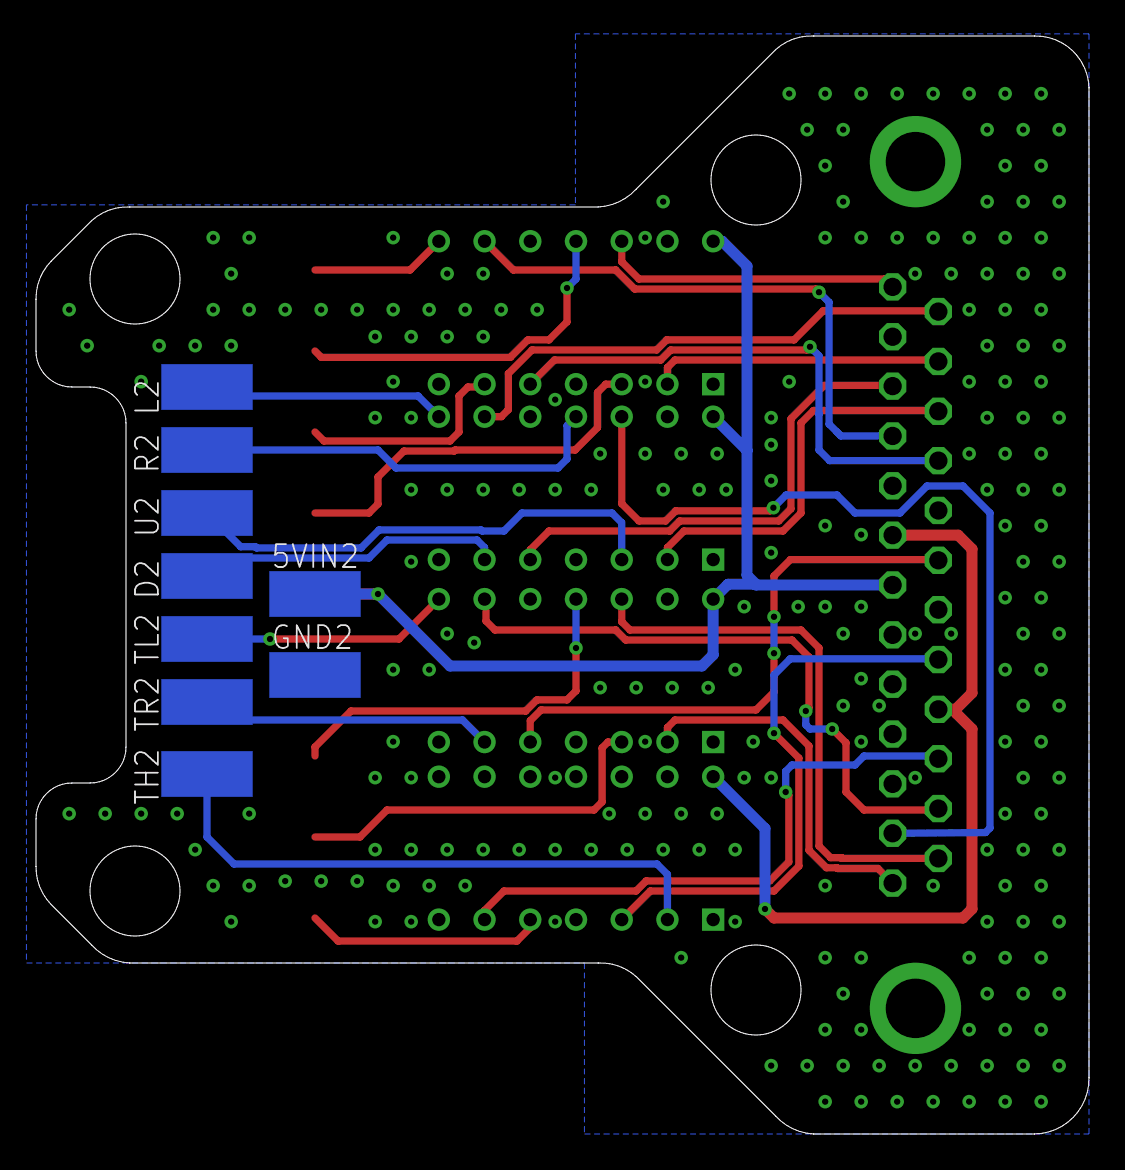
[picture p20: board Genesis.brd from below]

Board: 2 copper layers, 58.5 x 61.0 mm, 23 parts (9 on the bottom side), 31 nets.

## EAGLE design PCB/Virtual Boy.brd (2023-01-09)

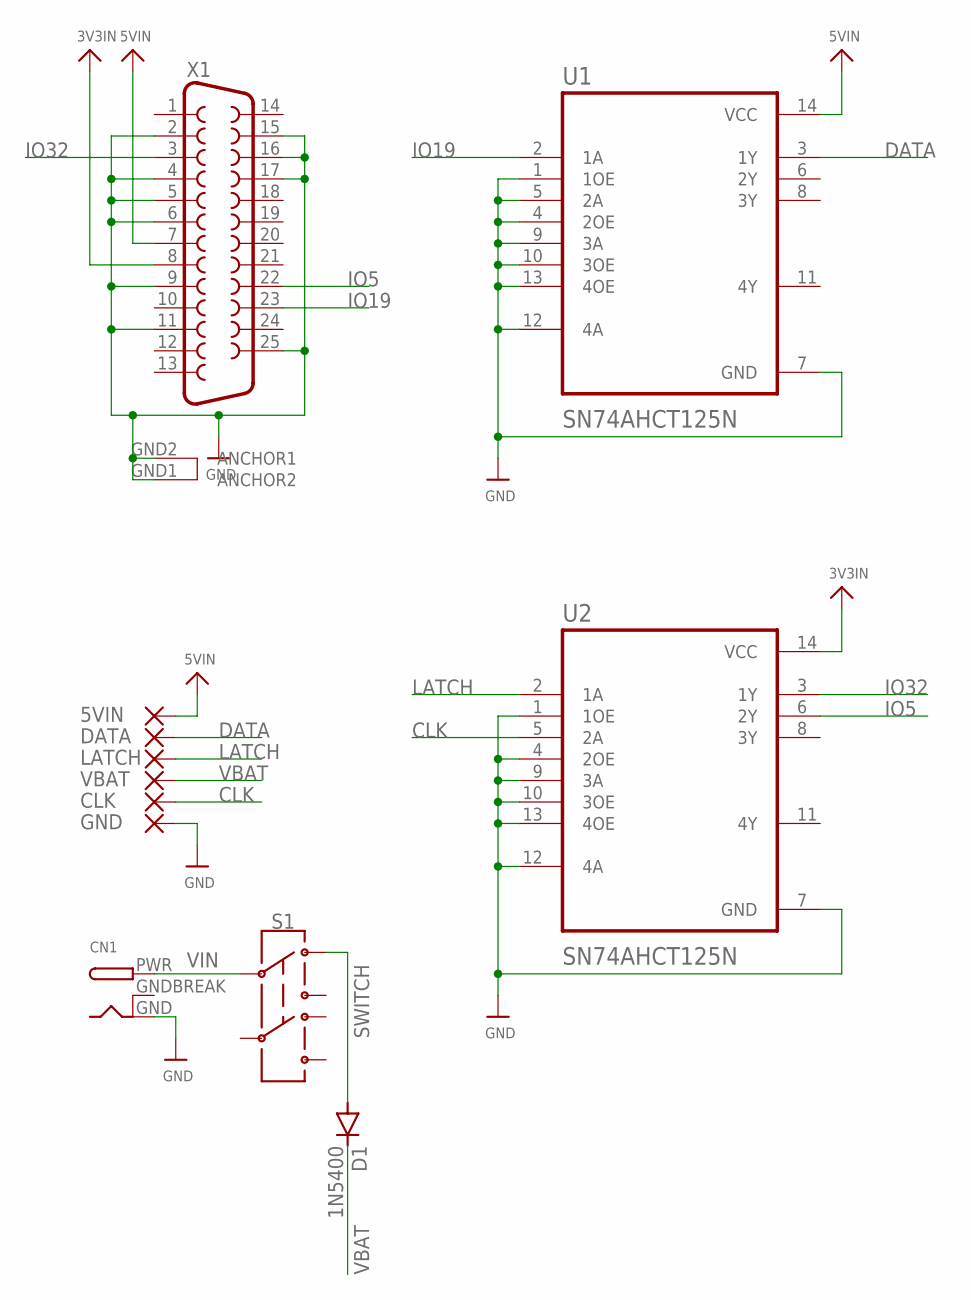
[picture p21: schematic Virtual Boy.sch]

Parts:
5VIN: SMD5; SMD2,54-5,08
CLK: SMD5; SMD2,54-5,08
CN1: DCBARRELPTH; DCJACK_2MM_PTH
D1: 1N5400; DO201-15
DATA: SMD5; SMD2,54-5,08
GND: SMD5; SMD2,54-5,08
LATCH: SMD5; SMD2,54-5,08
S1: SWITCH-DPDT-PTH-GPI-152-3013; SWITCH_DPDT_PTH_GPI-152-3013
U1, U2: SN74AHCT125N; DIP794W45P254L1969H508Q14
VBAT: SMD5; SMD2,54-5,08
X1: DB25_FEMALEHP; F25HP

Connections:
3V3IN: U2.14 (VCC), X1.8
5VIN: 5VIN.1, U1.14 (VCC), X1.7
CLK: CLK.1, U2.5 (2A)
DATA: DATA.1, U1.3 (1Y)
GND: CN1.GND, GND.1, U1.1 (1OE), U1.4 (2OE), U1.5 (2A), U1.7 (GND), U1.9 (3A), U1.10 (3OE), U1.12 (4A), U1.13 (4OE), U2.1 (1OE), U2.4 (2OE), U2.7 (GND), U2.9 (3A), U2.10 (3OE), U2.12 (4A), U2.13 (4OE), X1.2, X1.4, X1.5, X1.6, X1.9, X1.11, X1.15, X1.16, X1.17, X1.25, X1.GND1 (ANCHOR2), X1.GND2 (ANCHOR1)
GNDBREAK: CN1.GNDBREAK
IO5: U2.6 (2Y), X1.22
IO19: U1.2 (1A), X1.23
IO32: U2.3 (1Y), X1.3
LATCH: LATCH.1, U2.2 (1A)
SWITCH: D1.A, S1.10 (1)
VBAT: D1.C, VBAT.1
VIN: CN1.PWR, S1.C@1 (2)

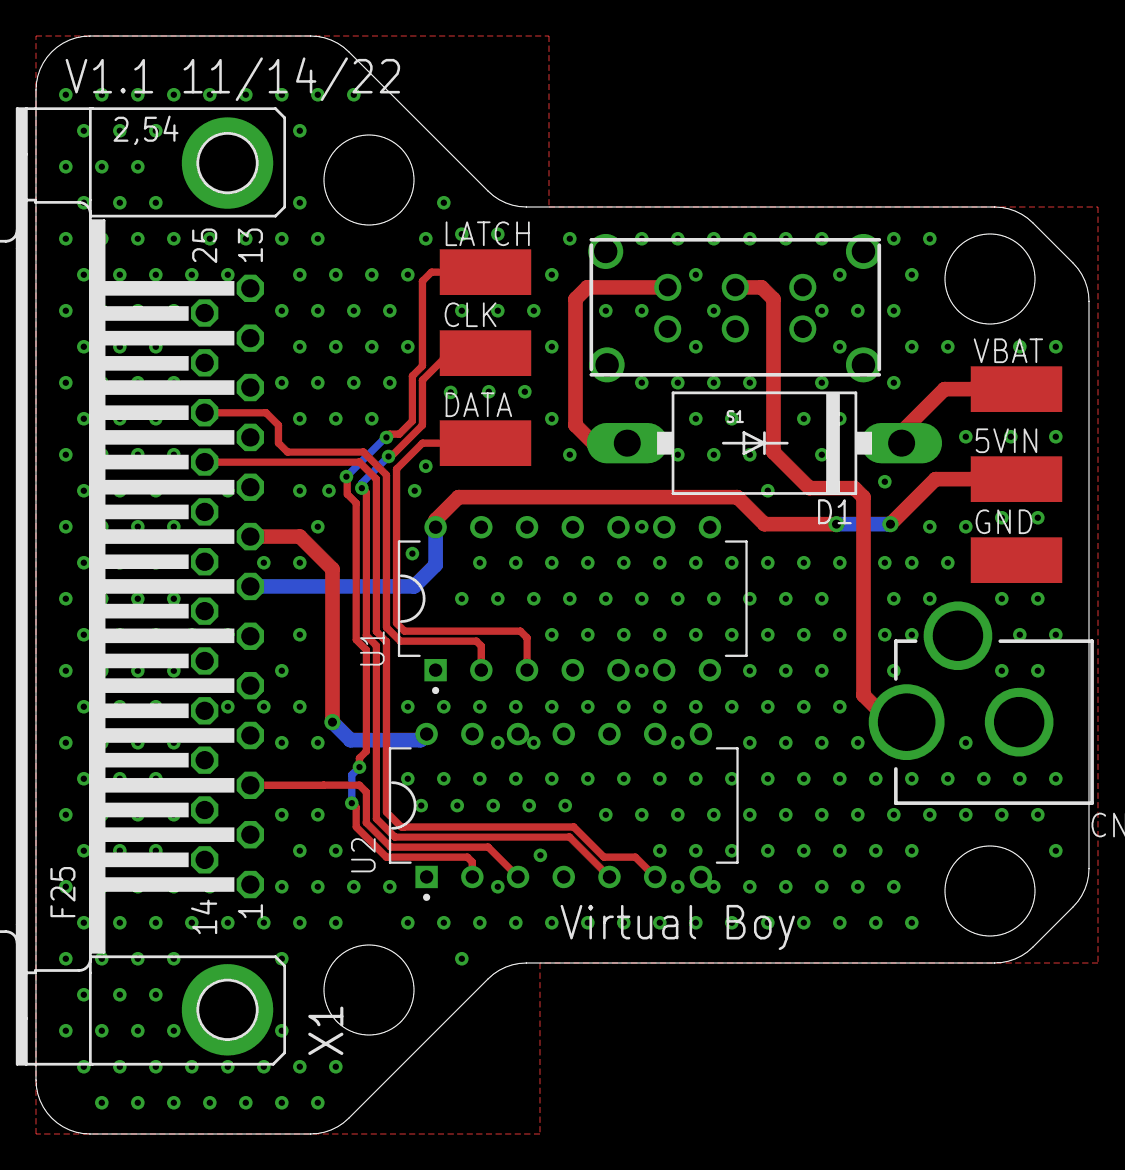
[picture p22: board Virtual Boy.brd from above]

Board: 2 copper layers, 58.5 x 61.0 mm, 12 parts (0 on the bottom side), 12 nets.

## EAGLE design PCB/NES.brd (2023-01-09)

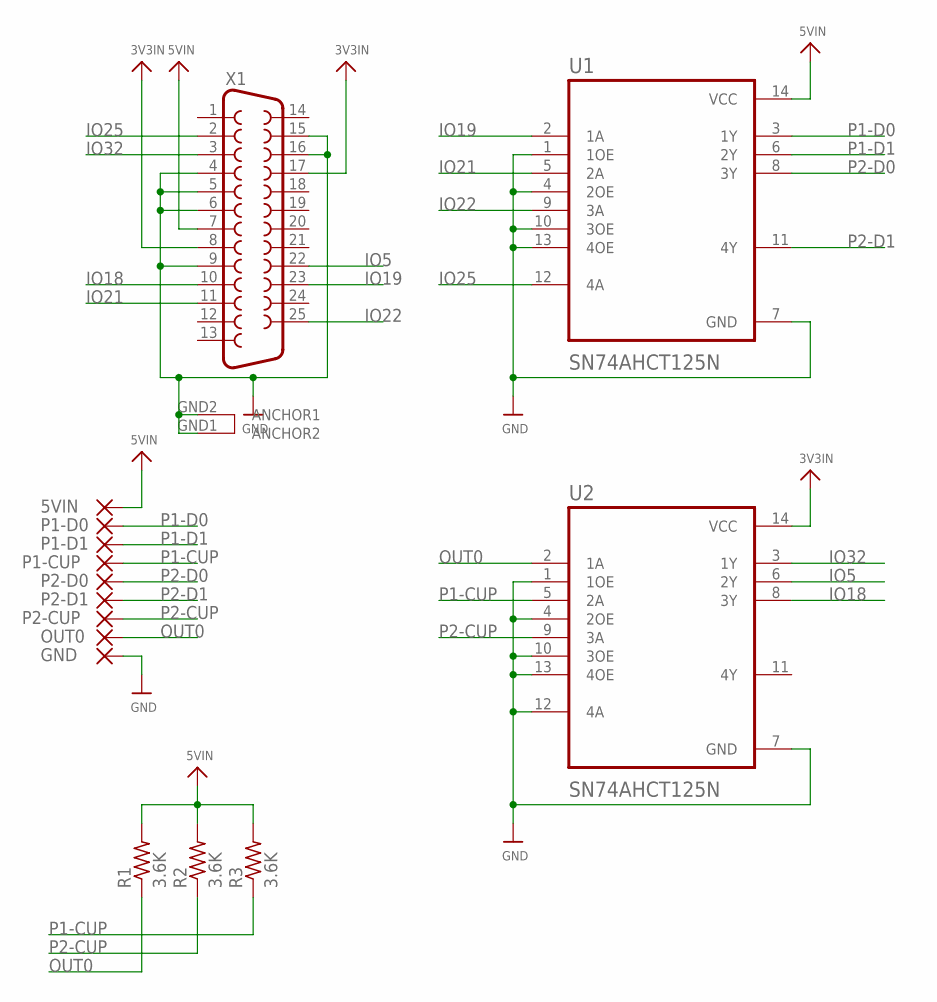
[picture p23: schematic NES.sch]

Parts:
5VIN: SMD5; SMD2,54-5,08
GND: SMD5; SMD2,54-5,08
OUT0: SMD5; SMD2,54-5,08
P1-CUP, P1-D0, P1-D1, P2-CUP, P2-D0, P2-D1: SMD5; SMD2,54-5,08
R1, R2, R3: 3.6K; R1206
U1, U2: SN74AHCT125N; DIP794W45P254L1969H508Q14
X1: DB25_FEMALEHP; F25HP

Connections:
3V3IN: U2.14 (VCC), X1.8, X1.17
5VIN: 5VIN.1, R1.2, R2.2, R3.2, U1.14 (VCC), X1.7
GND: GND.1, U1.1 (1OE), U1.4 (2OE), U1.7 (GND), U1.10 (3OE), U1.13 (4OE), U2.1 (1OE), U2.4 (2OE), U2.7 (GND), U2.10 (3OE), U2.12 (4A), U2.13 (4OE), X1.4, X1.5, X1.6, X1.9, X1.15, X1.16, X1.GND1 (ANCHOR2), X1.GND2 (ANCHOR1)
IO5: U2.6 (2Y), X1.22
IO18: U2.8 (3Y), X1.10
IO19: U1.2 (1A), X1.23
IO21: U1.5 (2A), X1.11
IO22: U1.9 (3A), X1.25
IO25: U1.12 (4A), X1.2
IO32: U2.3 (1Y), X1.3
OUT0: OUT0.1, R1.1, U2.2 (1A)
P1-CUP: P1-CUP.1, R3.1, U2.5 (2A)
P1-D0: P1-D0.1, U1.3 (1Y)
P1-D1: P1-D1.1, U1.6 (2Y)
P2-CUP: P2-CUP.1, R2.1, U2.9 (3A)
P2-D0: P2-D0.1, U1.8 (3Y)
P2-D1: P2-D1.1, U1.11 (4Y)

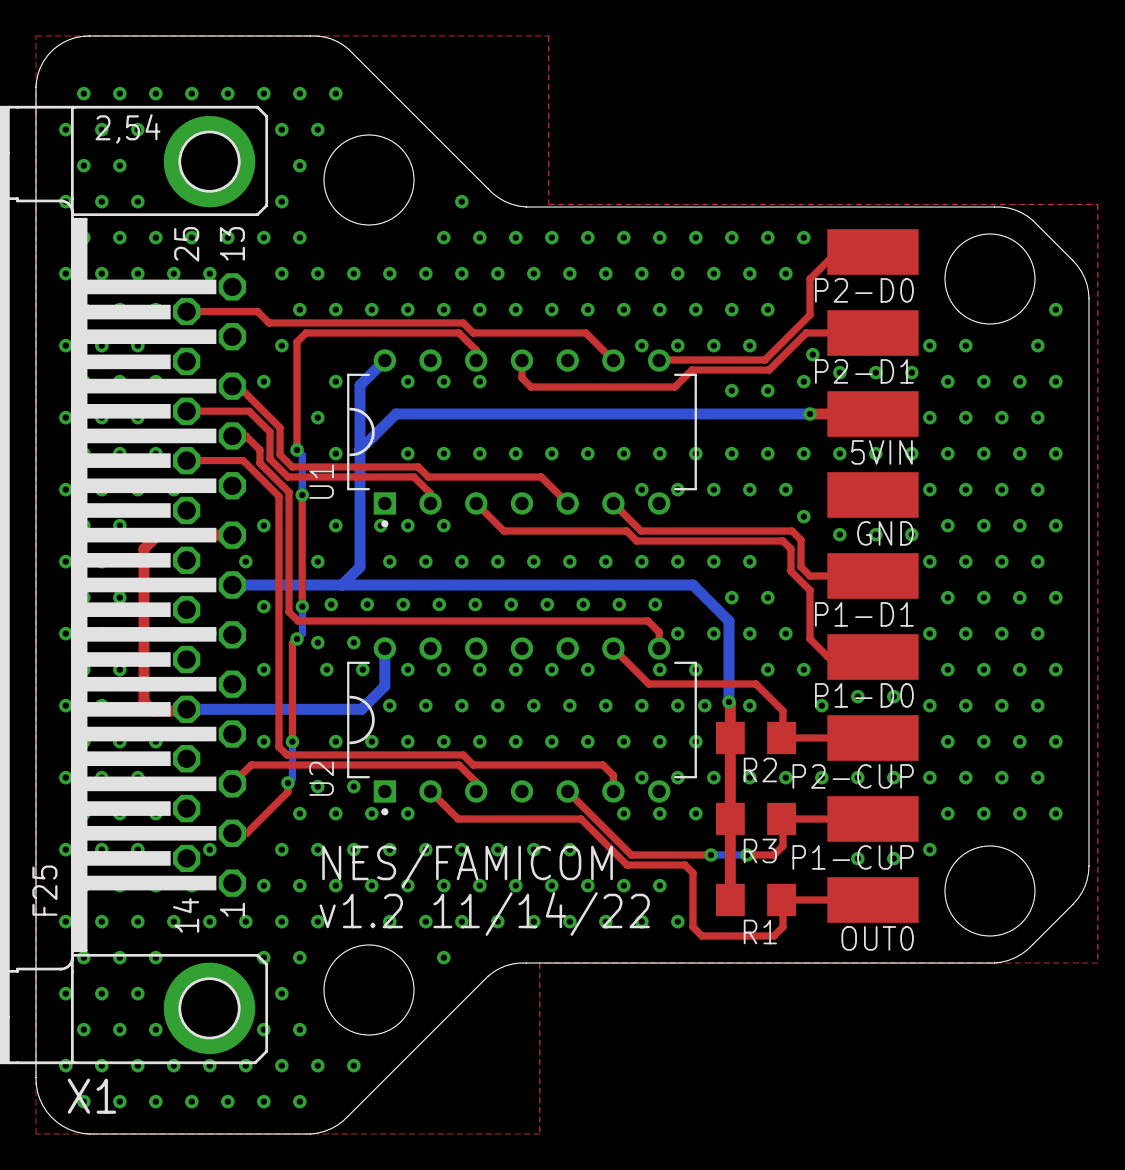
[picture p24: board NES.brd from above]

Board: 2 copper layers, 58.5 x 61.0 mm, 15 parts (0 on the bottom side), 17 nets.

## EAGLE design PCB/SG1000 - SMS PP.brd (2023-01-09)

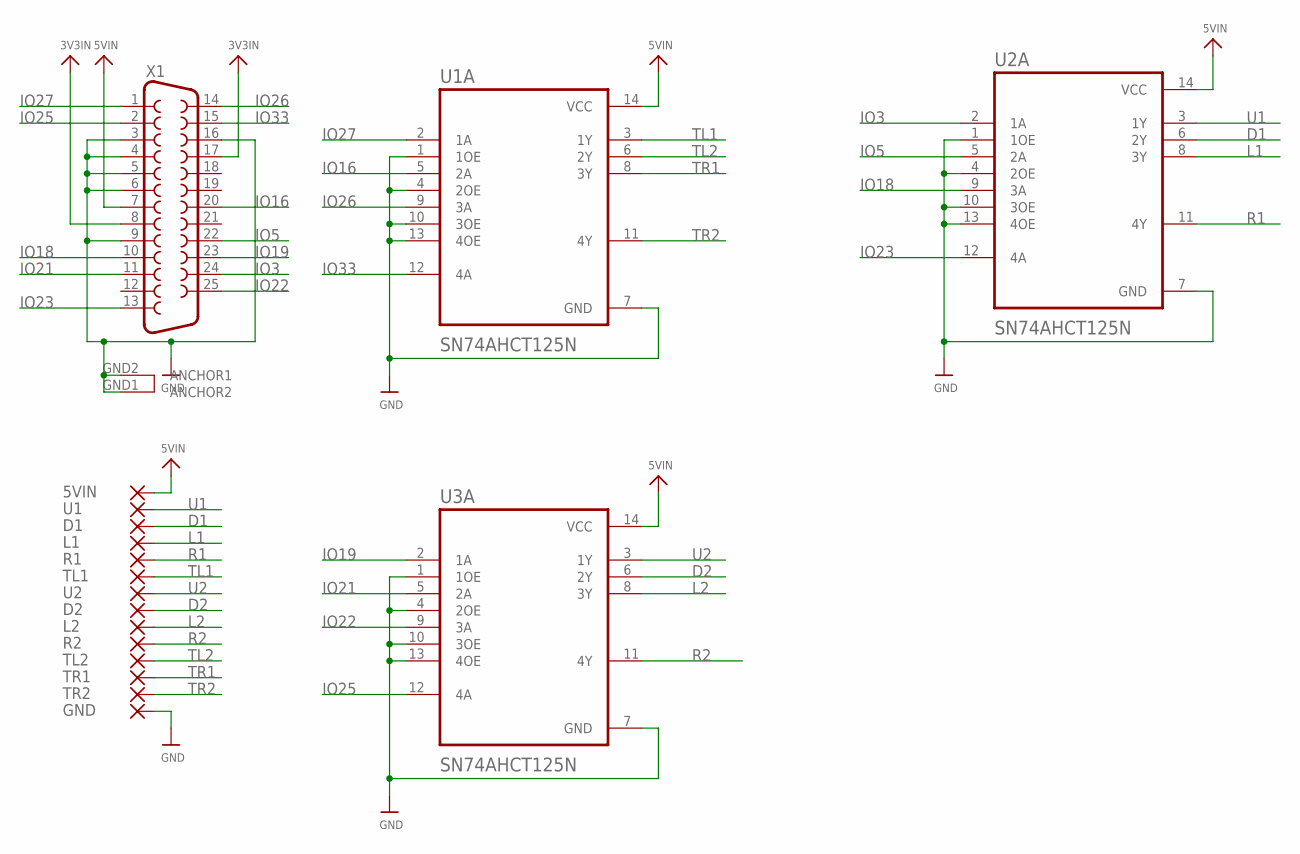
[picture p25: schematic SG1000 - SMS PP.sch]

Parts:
5VIN: SMD5; SMD2,54-5,08
D1, D2: SMD5; SMD2,54-5,08
GND: SMD5; SMD2,54-5,08
L1, L2: SMD5; SMD2,54-5,08
R1, R2: SMD5; SMD2,54-5,08
TL1, TL2: SMD5; SMD2,54-5,08
TR1, TR2: SMD5; SMD2,54-5,08
U1, U2: SMD5; SMD2,54-5,08
U1A, U2A, U3A: SN74AHCT125N; DIP794W45P254L1969H508Q14
X1: DB25_FEMALEHP; F25HP

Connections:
3V3IN: X1.8, X1.17
5VIN: 5VIN.1, U1A.14 (VCC), U2A.14 (VCC), U3A.14 (VCC), X1.7
D1: D1.1, U2A.6 (2Y)
D2: D2.1, U3A.6 (2Y)
GND: GND.1, U1A.1 (1OE), U1A.4 (2OE), U1A.7 (GND), U1A.10 (3OE), U1A.13 (4OE), U2A.1 (1OE), U2A.4 (2OE), U2A.7 (GND), U2A.10 (3OE), U2A.13 (4OE), U3A.1 (1OE), U3A.4 (2OE), U3A.7 (GND), U3A.10 (3OE), U3A.13 (4OE), X1.3, X1.4, X1.5, X1.6, X1.9, X1.16, X1.GND1 (ANCHOR2), X1.GND2 (ANCHOR1)
IO3: U2A.2 (1A), X1.24
IO5: U2A.5 (2A), X1.22
IO16: U1A.5 (2A), X1.20
IO18: U2A.9 (3A), X1.10
IO19: U3A.2 (1A), X1.23
IO21: U3A.5 (2A), X1.11
IO22: U3A.9 (3A), X1.25
IO23: U2A.12 (4A), X1.13
IO25: U3A.12 (4A), X1.2
IO26: U1A.9 (3A), X1.14
IO27: U1A.2 (1A), X1.1
IO33: U1A.12 (4A), X1.15
L1: L1.1, U2A.8 (3Y)
L2: L2.1, U3A.8 (3Y)
R1: R1.1, U2A.11 (4Y)
R2: R2.1, U3A.11 (4Y)
TL1: TL1.1, U1A.3 (1Y)
TL2: TL2.1, U1A.6 (2Y)
TR1: TR1.1, U1A.8 (3Y)
TR2: TR2.1, U1A.11 (4Y)
U1: U1.1, U2A.3 (1Y)
U2: U2.1, U3A.3 (1Y)

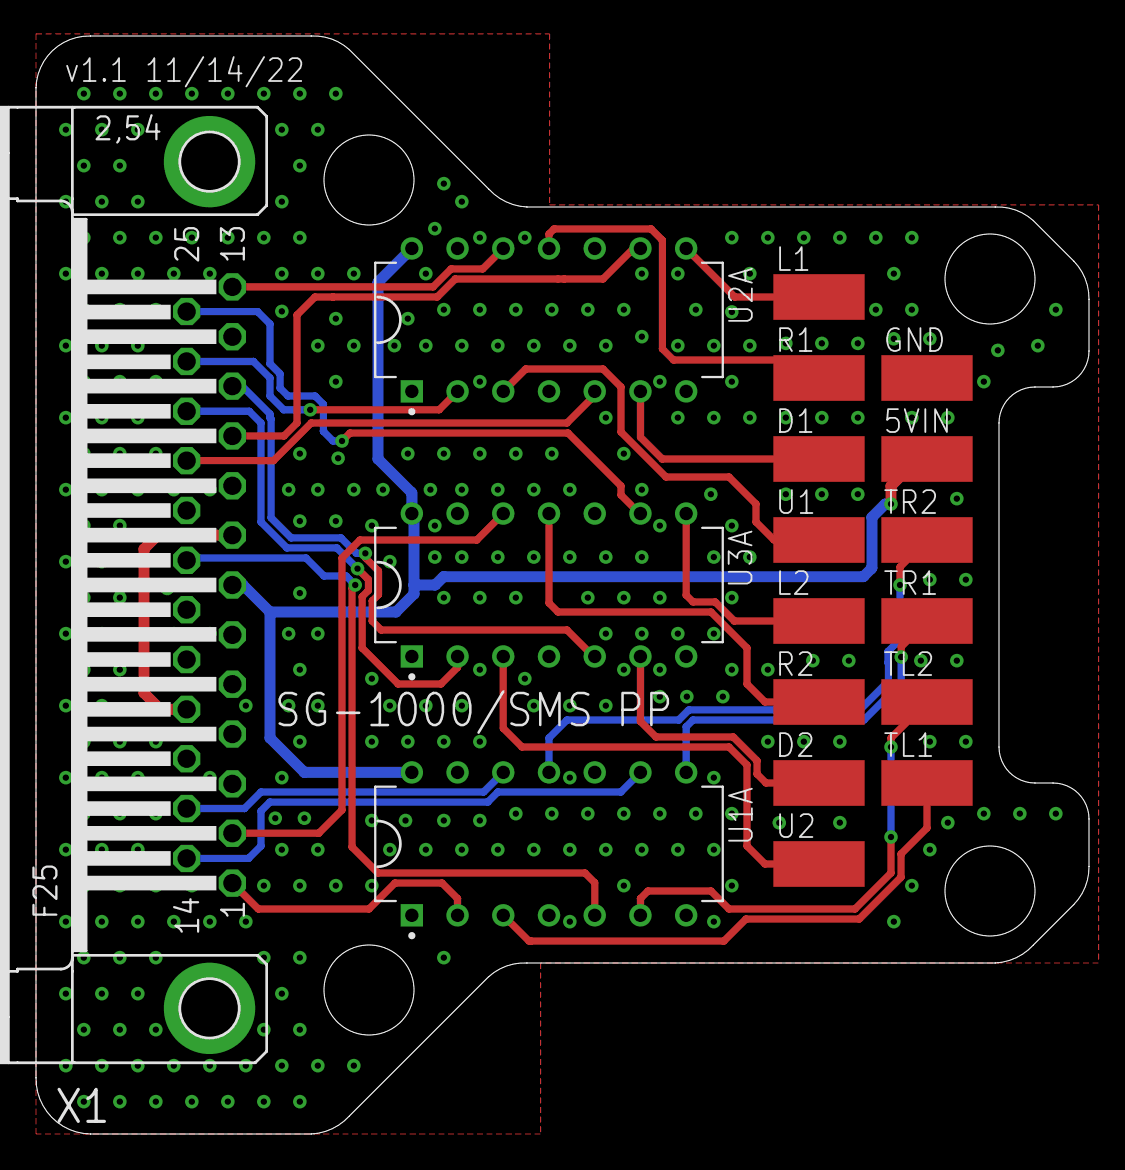
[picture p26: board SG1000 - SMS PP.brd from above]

Board: 2 copper layers, 58.5 x 61.0 mm, 18 parts (0 on the bottom side), 27 nets.

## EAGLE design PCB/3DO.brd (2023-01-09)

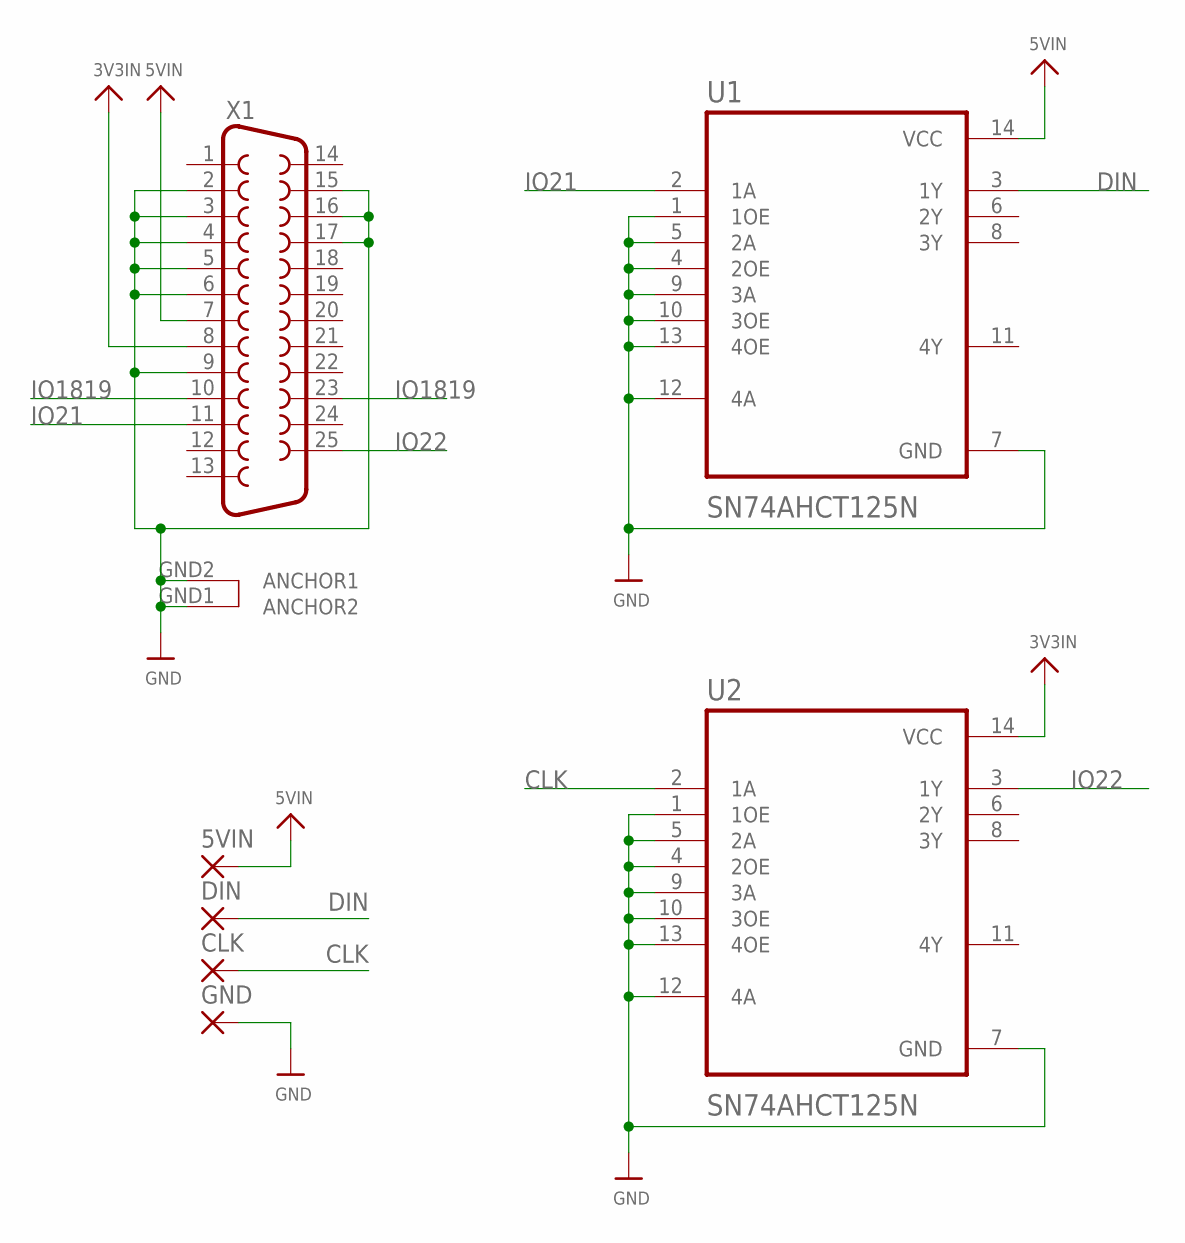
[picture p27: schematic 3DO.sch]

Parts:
5VIN: SMD5; SMD2,54-5,08
CLK: SMD5; SMD2,54-5,08
DIN: SMD5; SMD2,54-5,08
GND: SMD5; SMD2,54-5,08
U1, U2: SN74AHCT125N; DIP794W45P254L1969H508Q14
X1: DB25_FEMALEHP; F25HP

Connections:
3V3IN: U2.14 (VCC), X1.8
5VIN: 5VIN.1, U1.14 (VCC), X1.7
CLK: CLK.1, U2.2 (1A)
DIN: DIN.1, U1.3 (1Y)
GND: GND.1, U1.1 (1OE), U1.4 (2OE), U1.5 (2A), U1.7 (GND), U1.9 (3A), U1.10 (3OE), U1.12 (4A), U1.13 (4OE), U2.1 (1OE), U2.4 (2OE), U2.5 (2A), U2.7 (GND), U2.9 (3A), U2.10 (3OE), U2.12 (4A), U2.13 (4OE), X1.2, X1.3, X1.4, X1.5, X1.6, X1.9, X1.15, X1.16, X1.17, X1.GND1 (ANCHOR2), X1.GND2 (ANCHOR1)
IO21: U1.2 (1A), X1.11
IO22: U2.3 (1Y), X1.25
IO1819: X1.10, X1.23


Board: 2 copper layers, 58.5 x 61.0 mm, 7 parts (0 on the bottom side), 8 nets.

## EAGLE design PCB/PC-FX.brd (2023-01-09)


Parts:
5VIN: SMD5; SMD2,54-5,08
GND: SMD5; SMD2,54-5,08
P1-CLK, P1-DATA, P1-LATCH, P2-CLK, P2-DATA, P2-LATCH: SMD5; SMD2,54-5,08
U1, U2: SN74AHCT125N; DIP794W45P254L1969H508Q14
X1: DB25_FEMALEHP; F25HP

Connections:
3V3IN: U2.14 (VCC), X1.8
5VIN: 5VIN.1, U1.14 (VCC), X1.7
GND: GND.1, U1.1 (1OE), U1.4 (2OE), U1.7 (GND), U1.9 (3A), U1.10 (3OE), U1.12 (4A), U1.13 (4OE), U2.1 (1OE), U2.4 (2OE), U2.7 (GND), U2.10 (3OE), U2.13 (4OE), X1.2, X1.3, X1.4, X1.5, X1.6, X1.9, X1.11, X1.16, X1.17, X1.GND1 (ANCHOR2), X1.GND2 (ANCHOR1)
IO5: U2.8 (3Y), X1.22
IO18: U2.11 (4Y), X1.10
IO19: U1.2 (1A), X1.23
IO22: U1.5 (2A), X1.25
IO26: U2.6 (2Y), X1.14
IO33: U2.3 (1Y), X1.15
P1-CLK: P1-CLK.1, U2.9 (3A)
P1-DATA: P1-DATA.1, U1.3 (1Y)
P1-LATCH: P1-LATCH.1, U2.2 (1A)
P2-CLK: P2-CLK.1, U2.12 (4A)
P2-DATA: P2-DATA.1, U1.6 (2Y)
P2-LATCH: P2-LATCH.1, U2.5 (2A)


Board: 2 copper layers, 58.5 x 61.0 mm, 11 parts (0 on the bottom side), 15 nets.

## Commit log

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2022-02-27 PCB Updates/New Additions
    All existing PCBs had silkscreen updates and NES, Virtual Boy, PSX/PS2, Nintendo 64, Saturn have been added.
    [3DO.brd, 3DO.sch, BOM.xlsx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]
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2022-03-14 Datasheets, BOM Update, 3 New PCBs
    Added Datasheets for the Female/Male DB25 connectors
    Updated formatting on the BOM
    New PCBs:
    Added Nintendo 64 (Updated to 1.1, Moved VIN from 5V to 3V3)
    Added Sega Saturn (Updated to 1.1, Added 5V and GND Pads on bottom for Second player pads to ease install)
    Added NES
    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
    [BOM.xlsx, Nintendo 64.brd, Nintendo 64.sch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]
2022-03-14 Working On Virtual Boy PCB
    Need to find/make a cable that is not prohibitively expensive to test.
    [Virtual Boy.brd, Virtual Boy.sch]
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2022-03-14 Housing for PCBs
    This will include the housing designs for the Main PCB and all Aux PCBs
    [Housing.SLDPRT]
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2022-03-21 Preliminary CAD and STLs
    The CAD is finished and STL Created. I have ordered the Housings to make sure the snap fit will work as intended. Once I receive the housings and test them I will merge the branch if everything looks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
    [Aux Bottom 2 Player.STL, Aux Bottom 3DO.STL, Aux Bottom 4 Player.STL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]
2022-03-21 BOM Update
    Updated ESP32 Link to model with correct footprint in BOM
    [BOM.xlsx]
2022-03-22 PS2 Power Pin Swap
    The PCB could not detect the correct system using the 8V from the PS2 to the 5VIN on the ESP. Moving to the 3V3 from the PS2 to 3V3IN on the ESP corrected the issue and the PCB not works as intended.
    [PSX-PS2.brd, PSX-PS2.sch]
2022-03-23 Sharp Edge Fix for Shapeways
    The cutout for the DB25 connector on the top parts had a fillet applied to eliminate a sharp edge that would have caused printing problems.
    [Aux Top - 3DO.STL, Aux Top - Gamecube.STL, Aux Top - N64.STL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]
2022-03-23 Updated Pad Name for 3V3 input
    Pad name was still listed as P1-4/P2-4 which is the 8V pin, The pads have been renamed and order updated on the PCB
    [PSX-PS2.brd, PSX-PS2.sch]
2022-03-24 Power Pin addition
    After working with Darthcloud, it was revealed that some PS2 consoles have weak VIN on either the 8V or the 3V3. To make sure this PCB will work in either situation, I have added the 8V (Pad 3) pad b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
    [PSX-PS2.brd, PSX-PS2.sch]
2022-04-02 PCB Update for better Housing Fit
    All the PCBs were updated for better housing fitment.
    Common Changes across all PCBs:
    1. All Aux PCBs are now the exact same size. (there was a .1mm-.5mm Variance previous)
    2. All Aux PCBs Mounting holes are in the same location (there was a .05mm-.1mm Variance previous)
    3. The DB25 has been moved 1.2mm close to the edge of the PCB for better connection when in the housing.
    PCB Specific Updates:
    3DO - Rename Pads (Removed trailing numbers), Flipped U2 to match U1, Moved U1 & U2 to same coordinates as other 2 Component PCBs in collection.
    PCE & NES- Moved U1 & U2 to same coordinates as other 2 Component PCBs in collection.
    PS2/PSX & Saturn - Added Notch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
    [3DO.brd, 3DO.sch, Gamecube.brd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]
2022-04-02 Housing Update
    Widened the DB25 opening to allow male DB25 to fit over Female DB25 while in Housing, relocated PCB mounts to match PCB hole location in recent change.
    [Aux Bottom 2 Player.STL, Aux Bottom 3DO.STL, Aux Bottom 4 Player.STL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]
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2022-04-06 Add NeoGeo PCBs
    Added Neogeo/Jamma/Supergun PCBs. Both OD and PP versions
    [NeoGeo-JAMMA-Supergun OD.brd, NeoGeo-JAMMA-Supergun OD.sch, NeoGeo-JAMMA-Supergun PP.brd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]
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2022-04-06 Add Atari 2600 and SG-1000/SMS
    Added PCBs, Schematics and Gerbers for both PP and OD variants of the Atari 2600 and SG-1000/SMS (Both known as Parallel 2P)
    [Atari 2600 OD.brd, Atari 2600 OD.sch, Atari 2600 PP.brd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]
2022-04-15 Housing Update and Font Add
    Changed female snap fit on the main housing bottom to overrun the main counterpart on both sides by .5mm (was 1mm)
    Updated STLs for Main Housing Bottom and all AUX Tops as this was not done on last commit.
    Added Font used for console logos
    [Aux Top - 3DO.STL, Aux Top - Gamecube.STL, Aux Top - N64.STL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]
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2022-04-18 Added console variants to housing CAD and updated STLs
    Refreshed all Current STLs, Added 9 Variant AUX Covers to the Housing CAD
    New Variants Tops:
    Atari 2600, Atari 7800, Phillips CD-i, Famicom, Sega Genesis, Super Famicom, SNES, TurboGrafx 16 and Virtual Boy
    [Aux Bottom PCE-TG16.STL, Aux Bottom Single Player.STL, Aux Top - Atari 2600.STL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]
2022-04-19 Added New Systems Housing Variants and supporting fonts
    Finished Housing Variants for Atari Jaguar, Dreamcast, Neo Geo, PC-FX, Sega Master System, Sega Mega Drive and SG-1000
    Gerbers for all files have been created and fonts used added to the fonts folder.
    [Aux Top - Atari Jaguar.STL, Aux Top - Dreamcast.STL, Aux Top - Neo Geo.STL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]
2022-04-19 Changed Player Order for N64 and Gamecube
    Reversed the player order of the pads on the PCB, when installing in the housing the controller wires would twist. this resolves that issue.
    [Gamecube.brd, Nintendo 64.brd]
2022-04-20 Added Atari 7800 PCB and Gerber
    PCB was successfully able to be in the same footprint as all other variants. However it is the tightest design of all variants!
    [Atari 7800.brd, Atari 7800.sch]
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2022-04-20 Added Sega Genesis/Megadrive Multitap Support
    Added PCB/Gerber and Update SW CAD/ Added STLs for the Genesis/Megadrive Multitap version.
    [Aux Bottom 2 Player - Sega Multitap.STL, Aux Top - Sega Genesis - Multitap.STL, Aux Top - Sega Mega Drive - Multitap.STL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]
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2022-06-08 Fixed Omission of Main PCB in BOME PDF
    The print area was not correct in the XLS which then omitted the Main PCB. It has been updated.
    [BOM.xlsx]
2022-06-14 CD-i PCB/BOM Update
    Identified USB Mini from Digikey and add it to the BOM.
    Updated the PCB to match the layout for the USB Mini Connector and added a callout on the PCB that the connector is required for 5V Power.
    Updated project status to include the complete PC-FX Status.
    [BOM.xlsx, CDi.brd, CDi.sch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]
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2022-06-15 CD-i Housing Update
    Added a opening in the housing for the usb power port and offset the controller cable hole to the side. Includes the solidworks files and STLs
    [Aux Bottom CD-i.STL, Aux Top - CD-i.STL]
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2022-07-01 Adding Alternate Main PCB
    I added a alternate Main PCB that has a more standard (wider) ESP foorprint.
    The BOM has also been updated to include the Main ALT PCB
    [BOM.xlsx, Main - Wide ESP.brd, Main - Wide ESP.sch]
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2022-09-12 Updates from Issues 42/43/18
    Closed Issues 42 and 43 as Sega Genesis and PSX have been successfully tested and functional.
    Updated Dreamcast PCB per comment in Issue 18 - Reversed P1-P4 pads to match housing
    Updated Project Status to reflect #42 and #43 Complete
    [Dreamcast.brd, PSX-PS2.brd, Project Status.xlsx]
2022-11-14 Added exposed GND plane at DB25 anchors
    All PCBs have been update to have exposed GND plane pads for the DB25 anchor points.
    This resolves Issue 54
    [3DO.brd, 3DO.sch, Atari 2600 OD.brd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]
2022-11-14 Update BOM.xlsx
    Changed the Link for the Alt Wide Version to the correct 38 Pin version
    [BOM.xlsx]
2022-11-28 Wii Ext, NES/SNES mini PCB design complete (#59)
    * PCB Design
    Started design of Wii Ext & NES/SNES Mini PCBs
    I ordered the initial PCB and will update once I receive them
    Once the PCB is verified, I will work on the housing CAD
    * Adding USB-C Datasheet and Library
    * Update README.md
    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
    [BOM.xlsx, Main - Wide ESP.brd, Main - Wide ESP.sch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]
2022-12-28 Add Support for 5V PD Chargers (#61)
    Added 5.1K pull down resistors on the CC1 and CC2 to enable the use of a PD charger for 5V charging. Also cleaned up the PCB design and spread out pads for easier assembly.
    [Wiiext-NES Mini-SNES Mini.brd, Wiiext-NES Mini-SNES Mini.sch]
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2023-03-25 Silkscreen Change (#65)
    Added callout to connect cable shield to GND for PCB PCB. This fixes issues with the 6 button alternate config for the PCE
    [PCE - TG16.brd]

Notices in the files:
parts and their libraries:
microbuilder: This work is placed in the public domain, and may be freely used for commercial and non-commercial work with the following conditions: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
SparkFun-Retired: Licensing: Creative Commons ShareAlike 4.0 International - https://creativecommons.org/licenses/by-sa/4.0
